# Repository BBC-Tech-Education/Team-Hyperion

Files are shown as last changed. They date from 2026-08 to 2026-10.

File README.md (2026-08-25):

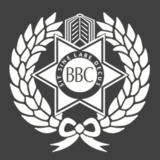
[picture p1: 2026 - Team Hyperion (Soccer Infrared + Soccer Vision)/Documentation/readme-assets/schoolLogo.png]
#  TEAM HYPERION 
### Brisbane Boys' College · RoboCup Junior Soccer Squad

<p align="center">
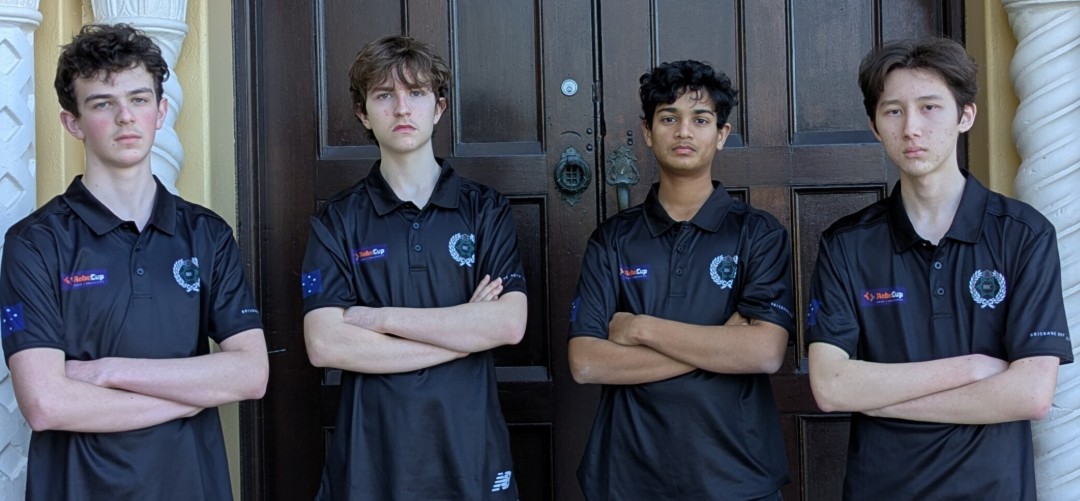
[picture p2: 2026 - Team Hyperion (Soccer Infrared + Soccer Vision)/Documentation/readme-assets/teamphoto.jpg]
Team Hyperion Banner
  
  <br>
  <b>Green. White. Black. Representing Australia.</b>
</p>

## 🤖 MISSION: BUILT TO COMPETE
Team Hyperion is a dedicated group of high school students (**Sam, Matthew, Luke, and Thomas**) from **Brisbane Boys' College** in Queensland, Australia. Originally competing internationally in Lightweight Soccer, we now compete in the **Soccer Vision League**—combining advanced robotics, autonomous alogorithms, custom sensor arrays, and precision engineering on the world stage.

---

## 🏆 ACHIEVEMENTS & COMPETITION HIGHLIGHTS

- **2026 RoboCup Junior International (Incheon, South Korea):**
  - **12th Place** — Individual Soccer (Improved ranking from 2025)
  - **4th Place** — SuperTeam Competition
- **2025 Australian National Competition:**
  - **Undefeated National Champions** — Reclaimed Australia's qualification spot for 2026
- **2025 RoboCup Junior International (Salvador, Brazil):**
  - **1st Place** — Lightweight SuperTeam World Champions
  - **14th Place** — Individual Lightweight Soccer

---

## 🚀 CURRENT CAMPAIGN (2026)
Having recently returned from the **2026 RoboCup Junior World Championship in Incheon, South Korea**, Team Hyperion is currently preparing for upcoming events, including the **Australian National Competition on the 3rd of October** in the Soccer Vision League.

---

## 🔗 CONNECT WITH US
Stay updated with our technical progress, media features, logbook, and competition results:

| Platform | Link |
| :--- | :--- |
| **🌐 Official Website** | [Visit Hyperion Online](https://team-hyperion-bbc-robotics.github.io/) |
| **📺 YouTube Channel** | [Watch Us Compete (@hyperion-bbcrobotics)](https://www.youtube.com/@hyperion-bbcrobotics) |
| **📓 Engineering Logbook** | [View Our Development Process](https://team-hyperion-bbc-robotics.github.io/logbook.html) |
| **✉️ Contact Email** | [bbchyperion@gmail.com](mailto:bbchyperion@gmail.com) |
| **📜 Legacy Sites** | [2024 Site](https://team-hyperion-bbc-robotics.github.io/2024) · [2025 Site](https://team-hyperion-bbc-robotics.github.io/2025) |

---

## 🛠️ THE TECHNOLOGY
Our custom-engineered robot stack is designed for high-speed autonomous play:
- **CAD & Mechanical Design:** Full 3D component renders in Fusion 360.
- **Lightweight League - Custom IR Ball Detection (Legacy Hardware):** TSSP77038 sensor ring tailored for direct IR tracking and direction strength processing under updated RCJ regulations.
- **Software & Vision:** Custom algorithms for ball tracking, autonomous navigation, and dynamic field positioning in the Soccer Vision League.

---

<p align="center">
  <i>"This is College" — Representing Brisbane Boys' College on the World Stage</i>
</p>

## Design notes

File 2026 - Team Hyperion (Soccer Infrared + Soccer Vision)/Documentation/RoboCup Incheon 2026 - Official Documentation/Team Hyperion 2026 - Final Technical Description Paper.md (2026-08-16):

## Timestamp

*Tijdstempel*

28-6-2026 16:23:18

## Email Address

*E-mailadres*

aparaj.bogahawatta@gmail.com

## TDP File

*TDP File Upload (Not required)*

## Team Name

*What is your team's name?*

Hyperion

## League

*What league do you participate in?*

IR League

## Country

*Where are you from?*

Brisbane, Queensland, Australia

## Contact

*If other teams have questions about your robot, now or in the future, what email address(es) can we publish along with this document for people to reach you?

(You can put in multiple email addresses, like multiple team members, an email for the whole team or both. Feel free to share other ways of communication like Discord handles)*

Team Hyperion Email: hyperionbbc@gmail.com

## Social Media

*Team Social Media Links (if you have any)*

YT: https://www.youtube.com/@hyperion-bbcrobotics

## Team Photo

*Upload a photo of your whole team with your mentor and robots

Note: This is not mandatory and will be published along with your TDP if you choose to upload something*



## Members & Roles

*What are the names of the team members and their role(s)?*

Matthew Adams: Electrical
Luke Atherton: Structural
Sam Garg: Software (Strategy)
Thomas McCabe: Software (Vision)

## Meeting Frequency

*How often did your team meet?
(e.g. 90 minutes once per week or a day every weekend.)*

During school term: 2.5 hours twice per week. During holidays: 4 hours three times per week

## Meeting Place

*Where did you meet to work on your robot?
(e.g. a robotics room at school, at some other place, one of your homes, school library etc.)*

We meet at our school’s designated robotics lab, the Brisbane Boys’ College Robotics Lab.

## Start Date

*When did your team start working on this year's robot?*

October 2025, after Australian Nationals

## Past Competitions

*Which RoboCupJunior competitions have you competed in and in which leagues?*

Brisbane Regional Competition 2026: Lightweight Soccer
Australian National Championship 2025: Lightweight Soccer
Queensland State Championship 2025: Lightweight Soccer
International Championship 2025: Lightweight Soccer
Australian National Championship 2024: Lightweight Soccer
Queensland State Championship 2024: Lightweight Soccer
Brisbane Regional Competition 2024: Lightweight Soccer

## Mentor Contribution

*Which parts of your work received the most contribution from your mentor?*

Our mentor assisted to debug electrical issues with the kicker PCB and our Out of bounds algorithm with the light sensors.

## Workload Management

*How did you manage the workload?*

By communicating via Teams, WhatsApp, and Discord, and using to-do lists and work logs, we managed our workload efficiently! This consistent workflow helps track our robot's progress, saves time, and cuts out redundant tasks.

## AI Tools

*Which AI tools did you use?*

We use Gemini for coding practices, field strategies, and docs, and Claude Code to design an aesthetic, secure website.

## Robot1 Overall

*Robot 1 Overall View*



## Robot1 Front

*Robot 1 Front view*



## Robot1 Back

*Robot 1 Back view*



## Robot1 Top

*Robot 1 Top View*



## Robot1 Bottom

*Robot 1 Bottom View*



## Robot1 Right

*Robot 1 Right View*



## Robot1 Left

*Robot 1 Left View*



## Robot2 Overall

*Robot 2 Overall View*



## Robot2 Front

*Robot 2 Front view*



## Robot2 Back

*Robot 2 Back view*



## Robot2 Top

*Robot 2 Top View*



## Robot2 Bottom

*Robot 2 Bottom View*



## Robot2 Right

*Robot 2 Right View*



## Robot2 Left

*Robot 2 Left View*



## Mechanical Design

*How did you design the mechanical parts of your robots?*

Using Autodesk Fusion 360, we upgraded our previous robot by adding a kicker, dribbler, and custom dual-layer omni wheels. To offset the added weight, we optimised existing components to minimise mass while ensuring structural strength. Key changes included designing a compact, high-stability wheel hub and heavily modifying the internal layout to fit the new mechanical systems alongside the PCBs and motors.

## Build Method

*How did you build your design?*

We manufacture parts using Bambu Lab 3D printers (PLA/ABS) and a CNC miller for 3mm aluminium plates. PCBs are ordered from JLCPCB, with components mainly sourced via Digikey. PCBs were hand soldered.

## Motors & Reason

*How many motors have you used and why?*

The robot features an X-shaped drive system with four 3D-printed-bracket-mounted Maxon DCX19 motors for omnidirectional movement without rotation. Overvolted at 12V for extra speed and torque, they power custom dual-layer omni wheels. These wheels use durable ABS frames and silicone-moulded rollers on metal cores, maximising traction, surface contact, and stability during competitive play.

## Kicker Design

*If your robot has a kicker, explain how you designed and built the mechanics of the kicker*

Our kicker uses a modified TAKAHA CB1037 solenoid with a custom 250-turn coil and a lightweight 3D-printed casing. The standard tip was replaced with a horizontal bar for reliable ball contact. Powered via a voltage booster that jumps 12V to 48V, it delivers a significantly stronger kick.

## Dribbler Design

*If your robot has a dribbler, explain how you designed and built the mechanics of the dribbler.*

Our dribbler uses a 3D-printed housing with a 1:4 speed-multiplying gear train, running the motor efficiently while spinning the roller at high velocities to save power. The roller features silicone molded around a 3D-printed rod to maximize grip and prevent ball slippage in the capture zone.

## CAD Files

*CAD design files*

https://github.com/Team-Hyperion-BBC-Robotics/Team-Hyperion/tree/main/2026%20(RCJ%20Lightweight%20Soccer%20and%20Open%20Soccer)/Hardware

## Mechanical Innovation

*Mechanical Innovation*

Our most significant innovation was a custom wheel hub, inspired by previous models, designed to attach our dual-layered omni wheels. This integration achieved better traction on the slippery felt field.

The hub directly modifies our existing design by adding a specialised internal groove for a square nut. This allows a bolt to tighten directly onto the motor's D-shaft, ensuring a secure mechanical connection that eliminates the risk of the wheel sliding off the axle.

## Mechanical Photos

*Photos of your mechanical designs highlights*




## Electronics Block Diagram

*Provide us with a block diagram of your robot's electronics*



## Power Circuit

*How does your power circuits work?*

A 12.6V LiPo battery powers the motors and kicker directly. Buck converters step this down to 5V (for the Teensys, camera, Bluetooth, and photogate) and 3.3V (for the IMU, IR sensors, and light ring), ensuring a stable, regulated power supply across all components.

## Motor Drive Circuit

*How do you drive your motors? Explain the circuits you use for that*

The robot uses five VNH7070 motor drivers powered directly by the battery. Four drivers control the drive system, receiving PWM commands from dual Teensy 4.1 microcontrollers to regulate each motor's speed and direction, enabling precise and powerful omnidirectional movement.

## Microcontroller & Reason

*What kind of micro controller or board do you use for your robot? Why did you decide to use this part for your robot? If you have more than 1 processor, explain each one separately.*

We use two Teensy 4.1 microcontrollers. One MCU reads the 24 TSSP sensors and communicates the ball data to the primary MCU via UART. The primary MCU reads the light sensors, IMU, receives the ball data and drives the motors and kicker.

## Motor Control

*How do you use your processor to move your motors?*

Exit VNH7070 standby: hold InA and InB HIGH for at least 20us. To drive, set one LOW, the other HIGH, while modulating PWM for speed. Both HIGH locks the motor; both LOW coasts. To coordinate, the processor uses a cosine function to calculate exact speed and direction for each motor.

## Ball Detection

*How does your ball detection sensors and/or camera[s] work?*

Our system detects a 40kHz IR ball using TSSP77038TR sensors. The ball's 24% duty cycle is polled over a 10ms window to locate it. To ensure stability, an Exponential Moving Average (EMA) filter smooths the data and remove high frequency noise on the readings. We then treat each value as a vector and sum them to determine the ball direction and strength.

## Line Detection

*How does your line detection circuits work?*

The robot has 48 LEDs/phototransistors. These are multiplexed using 3x 16 channel multiplexers for the primary MCU to read. 32 sensors are arranged in a ring and the other 16 are placed on the edge of the robot for early line detection.

## Navigation/Position Sensors

*What sensors do you use for navigation and how are these sensors connected to your processor? What sensors do you use to find your position in the field? What about the direction your robot faces?*

Connected to a Teensy processor, our robot uses an OpenMV N6 Camera via UART for absolute positioning, calculating coordinates using trigonometry on blue and yellow goals. For heading, a BNO055 sensor connects via I2C. By setting a baseline orientation upon startup or software reset, it continuously tracks our true direction relative to the field, ensuring dynamically accurate movement.

## Kicker Circuit

*How do you drive your kicker system? How does the circuit make the kicker work?*

A 12V supply is boosted to 48V to charge two parallel 4700μF capacitors. The microcontroller monitors this charge via a voltage divider. Upon a command, two N-channel MOSFETs discharge the energy through the solenoid to kick. A manual button routes power through a 50Ω resistor to safely de-energize.

## Dribbler Circuit

*How does your dribbler system work? What components and circuits did you use to drive it?*

Our dribbler system is a fifth Maxon motor which its circuit is integrated into our main board and is powered the same as the drive motors.

## Schematics

*Schematics of your robot*







## PCB

*PCB of your robot*





## Electronics Innovation

*Electronics Innovations*

A key innovation in our design is the custom dual-ring light sensor board, which provides a fast and reliable line avoidance system. The board utilizes a total of 48 sensors arranged in two concentric rings: an outer ring of 32 sensors and an inner ring of 16 sensors. 

The 32 sensors on the outer ring are divided into four distinct directional zones (front, back, left, and right) to provide rapid boundary detection and early warning alerts. The inner ring of 16 sensors serves as the primary trigger, signalling the robot to execute immediate corrective manoeuvres to remain within bounds. 

Integrating all 48 sensors into a single, consolidated printed circuit board (PCB) significantly reduces internal wiring. This layout minimizes the risk of loose connections and simplifies troubleshooting by allowing for rapid fault isolation.

## Circuit Photos

*Photo of your circuit boards highlights*







## Ball Detection Method

*How do you find where the ball is? How do you read the data from the ball detection sensors and/or camera?*

To locate the ball, our robot rapidly polls 24 IR sensors over a 20-millisecond window to count detected light pulses. These raw counts are normalised against the ball's duty cycle and smoothed by an EMA filter to prevent erratic spikes. Vector summation then resolves the exact relative angle. The magnitude is scaled to 0-100% for distance and sent via UART to the processor.

## Ball Catch Algorithm

*How does your algorithm work to catch the ball? Is there a difference between your robots in how they move towards the ball? Explain the differences.*

Our two-Teensy system uses a secondary Teensy to read IR sensors, pinpointing the ball's angle and distance without a camera. The primary Teensy uses this data to steer a smooth, curved orbit behind the ball, slowing for sharp turns and surging forward when perfectly aligned. This fluid approach replaces an older, twitchy method that ignored distance and glitched across the center line.

## Positioning Algorithm

*How do you use your sensors in your algorithm to find your position inside the field and how do you use that position to move your robots around?*

Using a camera to spot coloured goals, the robot calculates distance by size and notes the angle. Combining this with a digital compass, it pinpoints exact field coordinates. It navigates by plotting a straight line to the target, smoothly setting speed and direction. When the ball is off-field, this system centers the robot, ensuring the fastest route to the next ball.

## Line Algorithm

*How does your robot find the lines to stay inside the field? What algorithms do you use to avoid going out of bounds?*

Our robot multiplexes 48 light sensors, using dynamic calibration to isolate white lines. A Center of Mass algorithm generates a raw line vector from these active sensors. This vector is compass-corrected for field relativity and processed by a state machine tracking crossing depth. Finally, a PID controller uses this data to dynamically scale recovery speed in the exact opposite direction.

## Goal Algorithm

*What algorithms do you use to score goals? How do you use your kicker and dribbler to handle the ball?*

To score efficiently, our software merges orbit and goal-tracking algorithms using TSSP sensors and a camera. The orbit algorithm calculates an offset to position the robot behind the ball. Upon contact, an active dribbler firmly secures it, preventing wasted kicks and enabling passes. Using camera data, the robot dynamically aligns with the goal and triggers a powerful, calculated kick.

## Defense Algorithm

*What algorithms do you use to avoid the opponent team scoring? How do your robots defend your own goal?*

Our defender uses three PID controllers. A rotational PID keeps the robot facing away from the goal. The vertical PID controls depth via line sensors, using camera distance if the line is lost. The horizontal PID centres the robot, or laterally mirrors the ball to block shots. Combining these outputs into one resultant vector ensures fluid, omnidirectional movement to protect the goal.

## Robot Communication

*Do your robots communicate with each other? How do you use this communication to your advantage?*

The robots communicate via bluetooth assigning roles based on a 100-point score. The ball proximity (40pts), front attack cone (20), goal alignment (15), defensive distance (15), and battery health (10) are the factors the algorithm will consider. The robot with the highest score attacks. If one robot is taken off, then the remaining robot defends the goal.

## Software Innovation

*Software Innovations*

Our proudest innovation is a multi-stage IR sensor pipeline to track a 40kHz pulsed ball. We rapidly poll 24 TSSP77038TR sensors 500 times per 10ms window. To prevent jitter, an EMA filter blends this with historical data, halving standard deviation to 0.47. A vector summation calculates exact relative angles, while raw magnitude (110-130) is scaled to a 0-100% value. This information is sent to the main controller to determine motor movements.

## GitHub Link

*GitHub link*

https://github.com/Team-Hyperion-BBC-Robotics/Team-Hyperion

## BOM

*Bill of Materials (BOM)*

[https://drive.google.com/open?id=1605ioj5zMtxmfVHzTSfSkzvatkaK7vDL](https://drive.google.com/open?id=1605ioj5zMtxmfVHzTSfSkzvatkaK7vDL)

## Cost

*How much did it cost you to build your robots?*

Robots: $3,834 AUD (~$2,530 USD)

Spares & Experiments: $1,550 AUD (~$1,023 USD)

Environment: $0 AUD (Reused)

Total: $5,384 AUD (~$3,553 USD)

Conversion rate: 1 AUD = 0.66 USD

## Funding

*How did you gathered the funds to build the robots?*

100% School

## Affordability

*How affordable was it to compete in RoboCupJunior Soccer?*

5

## Answer Check

*Have you checked all of your answers?*

Yes!

## Publication Consent

*We publish TDPs and posters during or after the competition as described in the beginning*

Yes, we acknowledge everything submitted in the above form can be published.

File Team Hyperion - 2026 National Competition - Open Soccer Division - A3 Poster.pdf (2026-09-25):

# TEAM HYPERION

# Brisbane Boys’ College - Open Soccer League - Australian National Competition

### Who are we?

We are Team Hyperion, a four-student robotics team from Brisbane Boys' College, and right now, our primary focus is gearing up for the National Competition in the Open Soccer Division. We have just returned from representing Australia at the 2026 RoboCup in Incheon, South Korea, where we secured 12th Place Individually and 4th Place in SuperTeam, which proudly builds on our 2025 run in Salvador, Brazil (14th Individually, 1st Place SuperTeam). Coming off those international campaigns in the Infrared league, we are currently executing rapid technical modifications to our robot system adjusting our 360° vision processing and movement algorithms to handle the new field conditions of the Open league. After a quick trial run during the Queensland state competition, we are incredibly excited to compete in the national competition this year.

Previous Competition
Experience

2026 Queensland States
2026 Internationals - South Korea 2026 Brisbane Regionals
2025 Australian Nationals -Canberra
2025 Queensland States
2025 Internationals - Brazil 2024 Australian Nationals -Queensland
2024 Queensland States
2024 Brisbane Regionals
+ Numerous Individual
RoboCup Competition
Experience

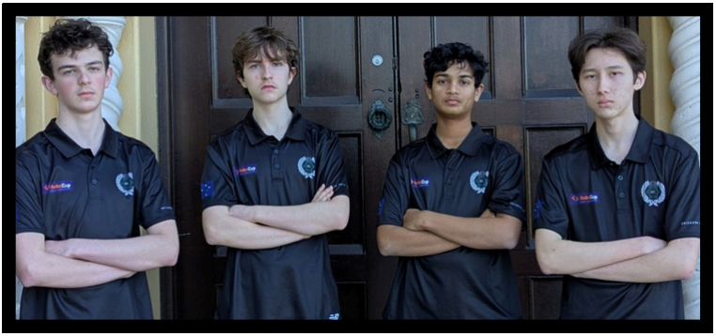
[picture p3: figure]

Our Team (Left to Right)

Thomas McCabe - Sensors/Software Luke Atherton - Structural/Hardware Sam Garg - Strategy/Software Matthew Adams - Electrical/Hardware

### Our Innovations - Light Sensor Board & Kicker “Video Game” Software

Hardware Innovation: The Light Sensor Board
The Light Sensor Board features 48 distinct component groups, each equipped with phototransistors, LEDs, resistors, and smoothing capacitors. These sensors are strategically arranged in a circular pattern ahead of the wheels to optimise a defender's positioning near the goal box, while 16 outer groups are divided into four segments between the wheels to ensure rapid line detection and response. To manage this dense array efficiently, all sensor signals are routed through three 16-bit multiplexers. This hardware configuration successfully consolidates the multiplexed data into just four analog pins, significantly reducing the number of processor pins required for operation.

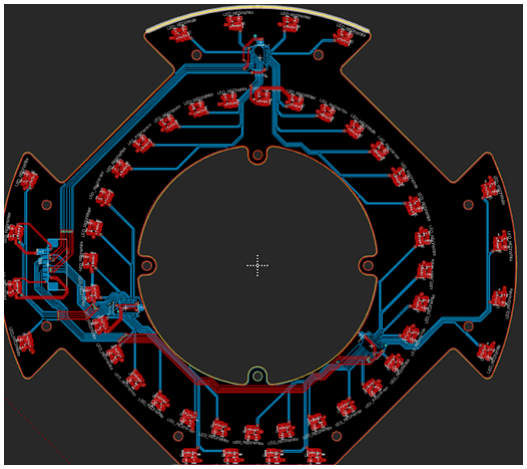
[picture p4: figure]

Software Innovations: The Ball Handling “Video Game” Software
The Kicker Software operates almost like a video game. This coded library coordinates the robot’s ability to safely shoot the ball automatically, acting as a strict “safety checklist” to prevent weak, accidental, or dangerous solenoid triggers. For example, one checklist item ensures the kicker has over 40V of stored power before firing. Just like an energy meter in a game, the robot holds a maximum of 5 kicks at any given time. When it does kick, it requires 20 seconds to recharge before that kick can be replenished, which prevents the hardware from overheating and causing a potential safety hazard. Additionally, the software enforces a mandatory 5s cooldown timer after every kick to allow the electronics to safely recover. To precisely time the shot, the kicker system uses a light gate made from a simple laser pointed directly into a light-dependent resistor (LDR). When a ball rolls into the capture zone, it blocks the beam of light from reaching the sensor. This causes the LDR's reading to drop, instantly signaling to the system that the ball has entered the capture zone. Finally, to ensure maximum hardware safety, a small LED on top of the robot’s PCB illuminates whenever there is voltage stored within the capacitors. If the capacitors still hold a charge when the robot is turned off, the system's fuse may blow. This warning LED lets team members know exactly when voltage is still present, ensuring the capacitors can be safely drained before powering down the robot.

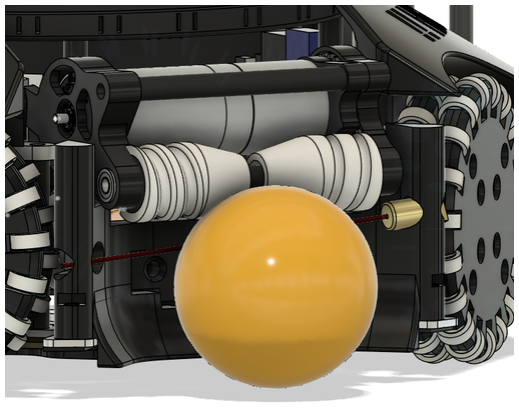
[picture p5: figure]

### Our Challenge – Ball Control & Field Vision

The Challenge: The robot struggled to maintain ball control and create scoring opportunities. Our previous momentum-based approach was ineffective under the international field restrictions and caused gradual damage through collisions with opponents. Additionally, the reflective-foil mirror used for goal and ball tracking was unreliable. Its steep viewing angle and surface warping created significant blind spots, limiting the camera’s ability to consistently detect and track the ball and goals.

The Solution: The team engineered a custom kicker and dribbler system. The dribbler uses a 3D-printed housing with a 1:2.81 speed-increasing gear ratio and high-grip silicone roller for reliable ball control. The kicker uses a modified TAKAHA solenoid with a custom hand-wound coil, lightweight 3D-printed mount, and wide plunger tip for consistent contact across the capture zone. A voltage booster increases the supply from 12 V to ~48 V, substantially increasing kicking power, while an integrated photogate detects ball capture.
A custom CNC-machined hyperbolic aluminium mirror was manufactured and polished. Its reflective curvature was calculated in Desmos based on the robot's dimensions and desired viewing range.

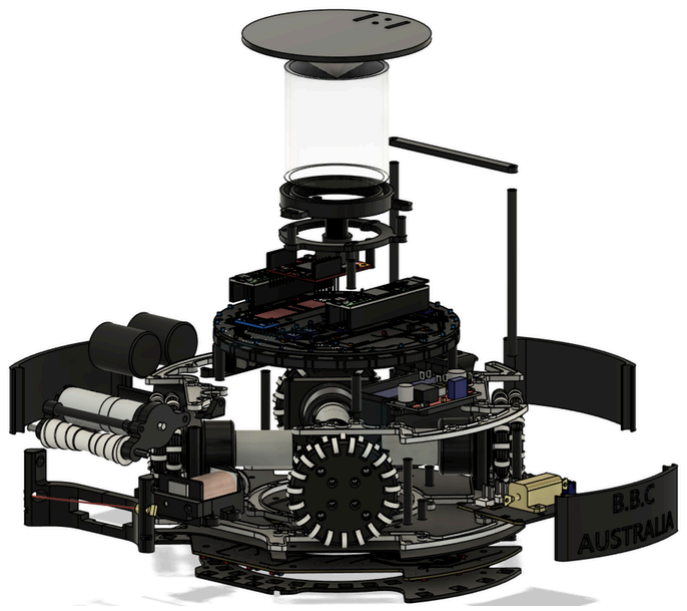
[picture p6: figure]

### What have we learnt throughout our time at RoboCup?

Throughout our time at RoboCup, we have experienced highs and lows. Whether that was the unparalleled thrill of placing in a competition, or the absolute panic of our robot’s wheels disintegrating right before a match, we have experienced a lot of what RoboCup has to offer. As a result of this, there are many things that we have learnt. This includes valuable technical and coding skills that we can take into our future professions and use to stand out in job applications. Moving beyond basic programming, we evolved into ‘multidisciplinary’ engineers. Structurally, we learned how to design resilient robots and account for the brutal physical forces our robots would face on the field. Electrically, we tackled power distribution, soldered reliable connections, and ensured clean signal integrity between components. By combining this hardware knowledge with complex software logic to process sensor data in milliseconds, we truly learned how to bridge the gap between digital code and the unpredictable physical world. However, the most profound lessons haven't just been technical. We have also grown significantly as a team over the years, which has given us the valuable ability to communicate, collaborate, and thrive under immense pressure. We learned how to divide tasks based on our individual strengths, trust one another's expertise, and navigate the high-stress environment of competition days by turning disagreements over design choices into constructive compromises. Most importantly, watching our hard work occasionally fall apart on the mat taught us true resilience. We learned to treat failures not as personal defeats, but as crucial data points to improve our iterative design. Ultimately, RoboCup was never just about making a robot function; it was a pressure cooker that forged us into better problem solvers and a more cohesive team, building a foundation of grit and synergy that will outlast any tournament.

## Our Website

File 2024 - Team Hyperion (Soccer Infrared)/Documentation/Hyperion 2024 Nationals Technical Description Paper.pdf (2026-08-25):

© RoboCup Junior Australia 2024 | 1 | P a g e

2024

## RCJA 2024 Rescue Line, Rescue Maze and Soccer Technical Description Paper

## Team Information: Challenge/Division: Lightweight soccer Team Name: Hyperion School: Brisbane Boys’ College State/Territory: Queensland - Brisbane Team Member Names:

If any team member had a specific role, please include this below.

## Member 1: Matthew Adams (Electrical) Member 2: Luke Atherton (Hardware) Member 3: Sam Garg (Software)

Robot Properties: (200 words recommended maximum, plus components list (if applicable))

Please describe the software (e.g. EV3 Block Code, Python) and hardware (e.g. Spike Prime, EV3, Raspberry Pi) you have used for your robot.

For each piece of software/hardware used, please give it a star rating out of 5 (1=very bad, would not recommend to other teams, 5=very good, would strongly recommend to other teams).

If you have used custom electronics for your robot, please include specific model/part numbers or web links, and a star rating for each.
Software
- The main language used for our robot is C++, however, python was used to communicate to a camera (in a library that is not used yet). An Arduino programming style was chosen to do this. A compiler was used so that the Arduino language can be understood by the robot. This compiler is named ‘platformio’ and is a commonly based system that is used for various programs.
C++ = 5
Arduino programming style = 4
Platformio = 5

Hardware
- Within the hardware process, Fusion 360 was used to design our full robot design, various individuals 3d printed components (such as the battery holder) and PCBs (such as the Light Sensor Board). Fusion also allowed for parts which weren’t printed to be factored into the visual design (such as various stand-offs between plates and components). Our robot mainly consists of a Base plate, Mid plate, Top plate, motor holders and TSSP holder made from PLA 3D print filament. With other smaller 3d printed parts to support other components, such as the battery holder, and 3d printed plates to support the power supply and Audino. There are 4 motors positioned in an X shape because of our omni wheels which allows the robot to have smooth omni-directional movement, being able to move in all directions with minimal issues, ensuring precision when positioning the robot on the field for optimal play. The central positioning of the power supply allowed for wires to connect easily to both the Audino and motor controllers.
Electrical
- The Electronic components consist of a power supply board, Light sensor Board and TSSP board. The Power Supply Board is a 60Lx40W(mm) board consisting of a JT60 connector that is connected to a 12V 1.3Amp Battery that is tucked in the robot securely, also there are multiple connections for power output on top of the board. The TSSP ring board is a circular ring with a hole in the centre to save space. The diameter of the board is 80mm the which is the exact size of the holder that we made. The TSSP ring is consisted of jumper wire pins and 12 TSSP58038 components in a circular patten pointed outwards. The Light sensor board is made of 16 Red LED’s and sensors in a circular patten.
Components List
- 3D Printed Custom Parts
- Custom made PCB’s (Light Sensor ring Board, Power Supply Board and TSSP ring board)

© RoboCup Junior Australia 2024 | 2 | P a g e
- Wheel rollers = 3
- Polulu 9.7:1 Metal Gearmotor 25Dx48L mm HP 12V https://www.pololu.com/product/3202 = 3
- Electrical Wiring
- Hot Glue
- Screws
- Nuts
- Bolts
- Standoffs = 5
- TSSP58038 TSSP58038 Vishay Semiconductor Opto Division | Sensors, Transducers | DigiKey (https://www.digikey.com.au/en/products/detail/vishay-semiconductor-opto-division/TSSP58038/4695717) = 4
- Arduino Jumper wires https://www.jaycar.com.au/150mm-plug-to-socket-jumper-leads-40-pieces/p/WC6028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 (https://www.jaycar.com.au/150mm-plug-to-socket-jumper-leads-40-pieces/p/WC6028) = 3
- MPU 9250 https://www.phippselectronics.com/product/mpu9250-9-axis-motion-sensor-module-accelerometer-gyroscopecompassmotion/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 (https://www.phippselectronics.com/product/mpu9250-9-axis-motion-sensor-module-accelerometer-gyroscope-compass-motion/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) = 3
- Arduino Mega 2560 = 4
- Multiplexer (for LSB) https://octopart.com/adg1206yruz-reel7-analog+devices-46514718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 (https://octopart.com/adg1206yruz-reel7-analog+devices-46514718?gad_source=1) = 3
Collaboration: (100 words recommended maximum)

### Please describe if your team has used any methodologies, software or systems to aid collaboration (working together). This could be related to the design, construction or

programming of the robot(s).
It is the overall desire of RoboCup Junior events that any technological and curricular developments will be shared with other participants after the event. Any developments including new technology and software examples, may be published on the RoboCup Junior website after the event, furthering the mission of RoboCup Junior as an educational initiative.
To collaborate we use Microsoft Teams, in the BBC Robotics Team (Organization)- we have our own designated channel. As well as this, we chat to each other using the teams group chat feature. (Also, by phone if teams are not available)

In addition to this; we use Fusion 360 to communicate our changes within our robot’s design. This allowed for all to make changes and access the full design, various components, and PCBs.

Not only this; but we use GitHub to communicate the changes made within our code, and so that all could access an updated version and previous versions of the code.

## Key Achievement & Area for Improvement: (300 words recommended maximum)

### Please describe one aspect of your robot your team is particularly proud of, and one

aspect you would like to further improve.
We are particularly proud of the way our TSSPs are designed- it can be seen that we use a PCB that links to the Arduino and power supply. Since we are a new team this year, PCBs are not regularly given- howeverthis was an exception, and we did not fail to deliver.

Another aspect that is particularly well done- is the overall design of the base & mid-plate. It is extremely organised and allows for a tight & compact robot, with components attaching both above and below the board. The various gaps in the board allows for reduced weight and allows for wires to connects to various components both above and below the mid-plate, such as between the motor controllers and the power supply. The mid-plate is compact as it has both components and standoffs above and below it; being attached to the motor brackets, motor controllers, standoffs to the baseplate, standoffs to the top-plate, standoffs to the power supply, and standoffs to the TSSP ring. Not only this- but our capture zone is the perfect size, allowing us to capture the ball within the rules- but also be able to dribble it.

In addition to this, we could introduce goal tracking to ensure that our robot faces the goal when we accelerate, to allow for more accurate goals, with more consistency.

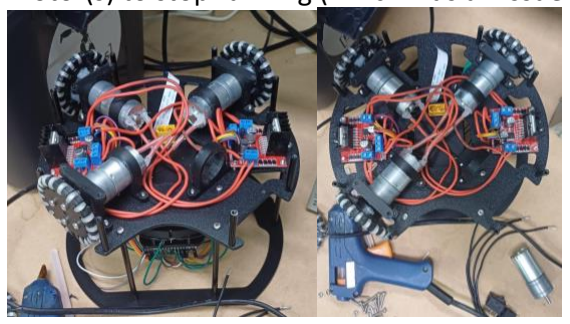
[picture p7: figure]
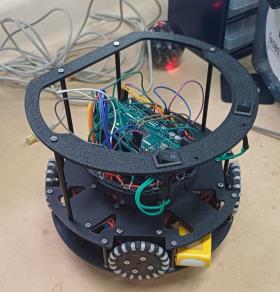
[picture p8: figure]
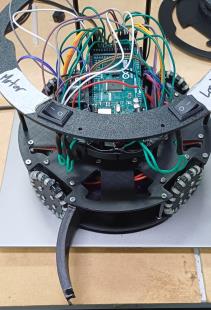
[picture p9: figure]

© RoboCup Junior Australia 2024 | 3 | P a g e

Photos and Design Documentation: (100 words recommended maximum, plus images)

### If there is a design drawing of the robot or if you have photos or notes of the

development process, please provide these as proof of your team’s learning.
These two images display the robot being assembled, with the wires from the motor controllers to the motors being soldered and hot glue gunned on to ensure they do not detach and cause the motor(s) to stop running (which was an issue we faced in earlier testing of the robot)

This image shows the assembled 1st robot. It consists of a top-plate, with 2 switches (one for motors and 1 for logic). It also has an Audino with wires to and from various components including the TSSPs on the TSSP ring and the power supply (located on a small plate just above the mid-plate). On the mid plate, above there are standoffs to the TSSP ring and top plate, and below there are the 2 motor controllers, motor brackets, and standoffs to the baseplate.

This image shows the robot with the battery holder attached (which stops the battery from falling out of the robot). The battery holder attaches to the standoffs as seen in the image, and it is also one of the later 3d printed components that were made. Previously, only tape was used but this was decided on as it would be more reliable and allowed for easier access the removal and reapplication of tape.

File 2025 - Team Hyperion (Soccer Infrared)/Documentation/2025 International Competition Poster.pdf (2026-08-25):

# Robocup Junior Soccer:

Lightweight Division | HYPERION
| BRISBANE BOYS COLLEGE

## > Robot Hardware Overview [Methods/Production/Design]

PHOTO HERE

# Method / Production / Design

# Abstract

Software Logic Flowchart

Electrical Logic Flowchart

# Data / Results / Discussion

## > Software Strategy [Methods/Production/Design]

## > Electrical Overview [Methods/Production/Design]

We use 2 customly designed PCBs which are an Intergreated Main Board and a Light Sensor Board.
1. Intergreated Main Board
The integrated main board includes a power supply circuit, Teensy 4.1, Open-MV H7 Plus, BNO055 IMU, Bluetooth HC-05 module, and a Light Sensor Board connected via an FFC connector. The power supply circuit is driven by a 3-cell 1300 mAh battery, which powers four VNH7070 motor controllers. It also includes 5V and 3.3V regulators that supply power to the microcontroller and 16 TSSP58038 sensors, respectively. The TSSP58038 sensors are arranged in a circular layout to provide a 360-degree view, allowing accurate detection of the ball’s position. The OpenMV H7 Plus was selected for its high detection speed, resolution, and frame rate.

The TSSP System library was custom-built by our team to meet specific design needs. It measures ball direction and strength by sampling each sensor 255 times, returning a value between 0 (no detection) and 255 (constant detection). A consistent 255 typically indicates a faulty sensor. If a single sensor fails, its value is replaced with the average of its two neighbouring sensors. However, software cannot correct clusters of failed sensors, which require hardware repair. Direction is now calculated using the top four TSSP readings, each weighted by its X and Y coordinates on the unit circle, with the angle derived using the arctangent function. Strength is determined through a weighted average: the strongest reading is multiplied by 3, the second by 2, and the third and fourth by 1, then divided by 7. This method improves accuracy and reliability in ball detection, with the example shown producing a strength of approximately 122.14 out of 255.

We utilise an OpenMV H7 Plus module, configured to a QQVGA resolution (160x120 pixels), which is then cropped to a 120x120 pixel square for processing. To identify both goals on the field, the robot employs the OpenMV camera to perform colour-based vision processing. Using Python, it runs the find_blobs function from the OpenMV image library, which detects coloured blobs that match a specified LAB threshold. The center coordinates of each detected blob are extracted and transmitted to the Teensy microcontroller via UART using the writechar function from the pyb UART library.

Hyperion is an Australian robotics team from Brisbane Boys’ College, competing in the 2025 RoboCup Junior Soccer Lightweight League. The team consists of four secondary school students who developed two fully autonomous soccer robots for the international competition. Building on experience from the 2024 season, our goal was to enhance the mechanical reliability, sensor accuracy, and gameplay consistency of our robots.
Each robot features custom-built omni-wheels for precise omni-directional movement, a vision system with a conical mirror and OpenMV camera for 360° goal tracking, and a light sensor array for field boundary detection. The robots are controlled using a Teensy 4.1 microcontrollers programmed in C++ via PlatformIO, with Micro-Python used for the OpenMV module. The robots were designed in Autodesk Fusion 360 and fabricated using 3D printing, CNC machining, and powered by custom-soldered PCBs.
To address limitations observed in past competitions, we refined the mirror geometry for improved goal visibility and replaced key structural components with aluminium to lower the centre of mass and increase impact resistance. We approached this season not just to compete, but to grow our technical capabilities and contribute to the wider RoboCup community. By documenting our designs and solutions for future teams to build upon, we aim to support RoboCup’s mission of fostering AI and robotics research.

When the robot detects a single cluster, it assumes the line is centered within that cluster and directly uses the cluster’s central angle as the estimated line direction. In the case where two distinct clusters are identified, the robot computes the circular average of their respective angles. This average is interpreted as the line direction, representing the midpoint between the two detected segments of the line. When three clusters are detected, the robot applies a more refined estimation method. It identifies the two outermost clusters based on angular separation and considers the remaining one as the central or inner cluster. First, it computes the average angle between each outer cluster and the inner cluster individually. These two intermediate values represent directional influences from each side of the line. Finally, it takes the average of those two values to derive a balanced and smoothed line direction, accounting for all three detected segments in a hierarchical manner.

An exponential function maps ball strength (distance to the ball) to the robot’s speed, enabling rapid acceleration when far and smooth deceleration when close. This improves control and reduces overshooting, unlike the slower-decelerating linear model previously tested. When the ball is directly ahead, the robot accelerates to top speed to maximise scoring.

To refine its movement path, the robot adjusts its trajectory using an exponential function based on ball direction. This creates a smooth, circular orbit around the ball, enabling fluid and strategic positioning for attack. Unlike using cases for where the ball is, and moving accordingly, this exponential function provides a more accurate and smooth orbit.

Ball Strength vs Movement Speed Graph

Ball Direction vs Movement Direction Graph

Previous Ball Direction Calculations vs Newly Innovated Ball Direction Calculations

Software

The first scenario prioritises ball strength, with the robot closer to the ball—indicated by higher strength—taking on the attacking role to maintain possession.

Bluetooth Switching, Scenario 1

Bluetooth Switching, Scenario 2

If the ball is behind the current attacker and closer to the defender, the robots switch roles minimising backtracking as the defender becomes the attacker and the original attacker takes a defensive role. This ensures the robot with the strongest visibility and least movement takes over the attack.

Camera Vision Example

Low/High Speed Moving Areas The attacker constantly advances toward the goal, guided by input from the onboard camera. It integrates this visual data into PID controllers, allowing it to quickly realign itself if displaced or rotated. Using the camera’s X-coordinate data, the robot estimates its lateral position on the field. When positioned closer to the sides—where the goal appears narrower—it reduces speed to enhance scoring accuracy. Conversely, it increases speed when directly in front of the goal, where the scoring angle is optimal.

Our defender uses three PID controllers to move effectively. The first is a rotation PID, which keeps the robot facing away from our goal at all times. This orientation ensures it is always prepared to intercept the ball as it approaches. The second is a vertical PID, which manages the robot's position relative to the goal. When the robot is far from the goal,
the control vector points at 180 degrees and increases in strength with distance. Conversely, when the robot is close to the goal, the vector strength decreases accordingly. The third PID responds to the ball’s position on the field. If the ball is to the right of the robot, it moves faster as the angle difference increases, and slower when the angle difference is smaller—though still quickly enough to position itself between the ball and the goal. When the ball is not present, the robot recentres itself in front of the goal using the compass, compensating for any offset caused by the rotation PID. If the ball moves behind the defender, the robot temporarily switches to attacker orbit behavior until the ball is once again in front.

Defender Vectors Example

1 Cluster Example | 2 Cluster Example | 3 Cluster Example

Flowcharts and Tools for Hardware and Software Hardware Tools

Software Tools

## Communication Tools

Autodesk
Fusion 360

Makera

Bambu Lab

Visual Studio Code

PlatformIO

OpenMV

Github

3D CAD
modelling
and PCB
circuit
design

CNC
machine
provider

Printing
3D models
for testing
& refining
Intergrated Main Board Fusion Design | Light Sensor Board Fusion Design
2. Light Sensor Board
The Light Sensor Board is comprised of 32 clusters of components, including phototransistors and LEDs arranged concentrically, and two 4-bit MUX506IPW to reduce Teensy pin usage. The Light Sensor Board allows our robot to distinguish boundary lines of the field (out of bounds, goal box) and specific edge cases where cross-shaped Light Sensor Boards cannot handle.

Aluminium Plate Replacement
We replaced PLA with aluminium 6061 for the mid and base plates to improve structural strength and gameplay durability. This change was prompted by repeated failures during high-speed matches, where abrupt impacts with the goal and other robots caused the PLA plates to crack or break, particularly at stress-concentrated regions.

Both of our robots are built on a shared design. Each robot features four motors, providing power, speed, and precise control for 360-degree movement. The goal of our robot design was to achieve a low centre of mass to improve acceleration, deceleration, and reduce tipping during turns. The frame was structured to compactly house all components without wasted space. We maintained a simple and focused design, prioritising only the components essential for consistent, reliable performance. Materials:
Three materials were used for the majority of the robot’s design: CNC-machined aluminium 6061, 3D-printed PLA, and 3D-printed ABS. The core structural plates for the robot were constructed from 3 mm thick CNC-machined aluminium, offering excellent strength, durability, and ductility, ensuring the robot’s structure remains intact after many collisions. The majority of other designed components were made using 3D-printed PLA due to ease of printing, decent strength and heat-resistant properties, and accessibility. 3D-printed ABS was used to construct the wheels, as, due to their close proximity and connection to the motors, they require very high heat resistance and greater durability compared to other printed components. Thus, ABS was used—as although it is more difficult to acquire and print, its superior performance in these properties makes it favourable for this component.

Vision System (1):
The vision system consists of a cone-shaped reflective mirror (1a), a clear acrylic tube (1b), an upward-facing OpenMV camera module (1c), and adjustable PLA mounting plates (1d).
- Mirror (1a) The mirror reflects a full 360° horizontal field of view down into the camera, allowing the robot to continuously track the goal from any position or orientation without needing multiple cameras.
- Tube (1b) The transparent acrylic tube connects the mirror and camera while allowing unobstructed light to pass through—unlike standoffs, it avoids introducing blind spots.
- Camera (1c) The OpenMV camera is programmed using MicroPython and processes the reflected image to determine the angle to the goal.
- Mount (1d) The adjustable plates allow for calibration of the mirror’s position to correct for alignment inconsistencies during manufacturing.

General Frame Design (2, 3, 4, 5):
The robot’s frame was designed around two main structural components:
- Top Plate (2) The top plate is 3D-printed in PLA and houses key switches and a handle for ease of access during matches.
- Battery Containment (3) The battery holder and a rear support wall between the mid and base plates, which secures the battery and prevents hardware failures caused by movement or impact.
- Mid & Base Plates (4 & 5) The mid plate and base plate, both made from CNC-machined aluminium to centralise mass low to the ground and improve stability during rapid movement.

Capture Zone (8):
The PLA-printed ball capture zone improves contact area with the ball, enabling more consistent control during movement and turns. Its curved design better matches the ball’s shape, reducing sudden contact and improving handling.

PCBs (7 & 10):
The PCB’s are designed in AutoDesk Fusion 360 and ordered through JLBPCB for fast and good quality boards. (More information in the Eletrical Overview)
- Light Sensor Board (7) The Light Sensor Board allows the robot to detect the boundary line and the Light sensor Board protector protects the Light Sensor Board from any debries left on the field.
- Main Board (10) The Main Board consists of the power supply, microcontrollers, motor controllers, bluetooth & camera.

Drive system (6: 6a, 6b, 6c):
The drive system consists of custom-made omni-directional wheels (6a), motor brackets (6b) and high-performance motors (6c)

The omni-wheels were designed with silicon-coated steel rollers mounted on ABS 3D-printed hubs for improved traction and durability.

Each wheel is powered by a DCX19 Maxon 9V motor (6c), due to its compact size and high torque output. The motors are fixed in place using custom brackets (6b), for alignment and structural stability.

CAD 3D Exploded view of overall Robot Structure In AutoDesk Fusion 360

3D Exploded view of Motor Mount In AutoDesk Fusion 360

Coding
software

Compiler
for microcontroller

Vision
programming
interface

Version
control &
collaboration

Discord

Microsoft
Teams

## Meet the Team:

Thomas McCabe | Luke Atherton | Samaksh Garg | Matthew Adams
Software & Documentation | Hardware & Structural | | Hardware & Electrical

Software &
Strategy

Team Communication and Collaboration, for scheduling sessions, progress updates, asking questions, and sharing files

Hardware

Mirror Dimension Simulation

Robots with PLA vs
Aluminium plates

Mass Increase and Centre of Mass Impact
- Aluminium plates added 101 g → Still under weight limit
- Extra mass lowered centre of mass
→ Improved stability during turns and acceleration
- Traction is the limiting factor for acceleration, not motor torque
→ Increased normal force enhanced grip without reducing speed
- Top plate remains PLA to minimise weight at higher elevations

Mirror Selection and Simulation
To maximise horizontal field of view and ensure uninterrupted vision of the goal, we investigated the optimal mirror shape and dimensions for our omnidirectional vision system.
Mirror Shape Investigation
- Cone-shaped mirror selected over 2D shapes (e.g. rectangles)
→ Reflects light from all horizontal angles into the camera → Enables full 360° vision around the robot
- Simplifies vision processing compared to using multiple cameras

Mirror Dimension Simulation
Fixed parameters: Base diameter (23.75 mm), vertical distance from camera to mirror base
Variable: Mirror height — determines reflection angle and field of view Goal: Find optimal mirror height for full field coverage
Method: Simulated ray reflections (mirror radius 2.375 cm) in Desmos
→ Adjusted mirror angle so reflected ray enters camera just below horizontal → Extended ray to floor (14 cm below camera) to find max range
Result: 16 mm mirror height → ~31 m viewing range (well beyond field, accounts for tolerances)

Innovations from 2024:
The main board was changed from multiple different PCBs to a single integrated PCB for easy access to all components and to limit the amount of space needed. The light sensor board was changed from a small ring with 16 groups of components to a ring surrounding the wheels of the robot with 32 groups of components to adapt to the different field and ruleset from the Australian Open in 2024.
PLA (previous) | Aluminium 6061 (current)
- Lightweight and easy to 3D print - Low yield strength (~60 MPa) and brittle - Fractures under stress, unsuitable for high-impact applications | - High mechanical strength (~270 MPa) and ductility - Plates deform slightly under stress rather than cracking - More reliable in high-impact applications
Our Website | Github Link

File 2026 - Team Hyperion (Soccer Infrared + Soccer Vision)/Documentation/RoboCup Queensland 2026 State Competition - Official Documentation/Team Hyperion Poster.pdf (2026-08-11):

# TEAM HYPERION

# Brisbane Boys’ College - Open Soccer League - Queensland State Competition

### Who are we?

We are Hyperion, a four-student robotics team from Brisbane Boys' College, and right now, our primary focus is gearing up for the Queensland Competition in the Open Soccer League. We have just returned from representing Australia at the 2026 RoboCup in Incheon, South Korea, where we secured 12th Place Individually and 4th Place in SuperTeam, which proudly builds on our 2025 run in Salvador, Brazil (14th Individually, 1st Place SuperTeam). Coming off those international campaigns in the Infrared league, we are currently executing rapid technical modifications to our robot system tweaking our 360° vision processing and movement algorithms to handle the new field conditions of the Open league. Despite the quick turnaround, we are incredibly excited to hit the state field and remain dedicated to sharing our open-source designs and workflows to help future teams master these advanced autonomous systems.

Previous Competition
Experience
2026 Internationals - South Korea
2026 Brisbane Regionals
2025 Australian Nationals -Canberra
2025 Queensland States
2025 Internationals - Brazil 2024 Australian Nationals -Queensland
2024 Queensland States
2024 Brisbane Regionals
+ Numerous Individual
RoboCup Competition
Experience


Our Team (Left to Right)

Thomas McCabe - Sensors/Software Luke Atherton - Structural/Hardware Sam Garg - Strategy/Software Matthew Adams - Electrical/Hardware

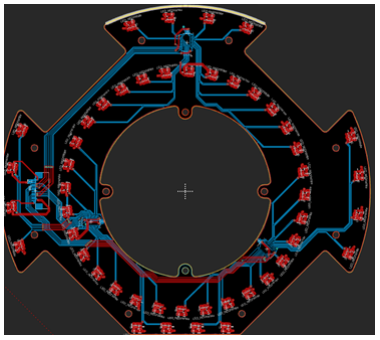
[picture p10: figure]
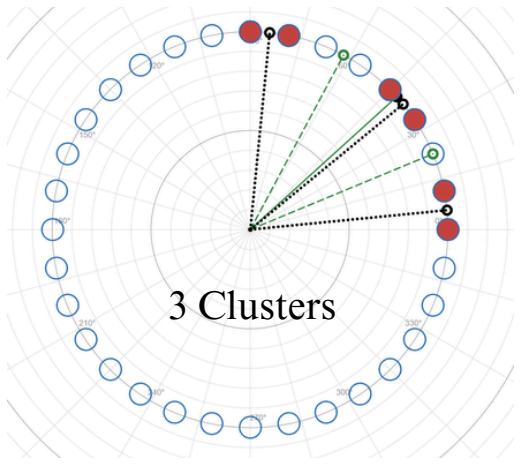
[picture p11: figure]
3 Clusters

### Our Innovation - Light Sensor Board

The Light Sensor Board features 48 distinct component groups, each equipped with phototransistors, LEDs, resistors, and smoothing capacitors. These sensors are strategically arranged in a circular pattern ahead of the wheels to optimize a defender's positioning near the goal box, while 16 outer groups are divided into four segments between the wheels to ensure rapid line detection and response. To manage this dense array efficiently, all sensor signals are routed through three 16-bit multiplexers. This hardware configuration successfully consolidates the multiplexed data into just four analog pins, significantly reducing the number of processor pins required for operation.

To find the direction of the line, the robot is simply trying to find the most accurate "middle" of whatever it currently sees. Depending on how many pieces (clusters) of the line the robot detects, here is what it does:
One Cluster: The line is straight at that cluster! The direction is just the center of that single piece.
Two Clusters: The line is in the middle of that cluster! The robot pinpoints exactly halfway between the two pieces.
Three Clusters: It completes a balancing act, where it finds the middle pieces and the two outside pieces. It calculates the halfway point between the middle and left side, and then the middle and right side. After doing this, it averages those two paths to get a smooth and balanced direction.

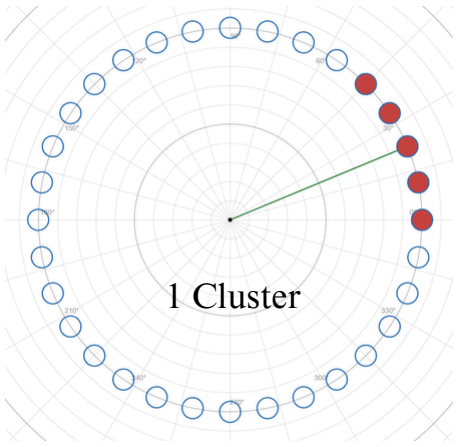
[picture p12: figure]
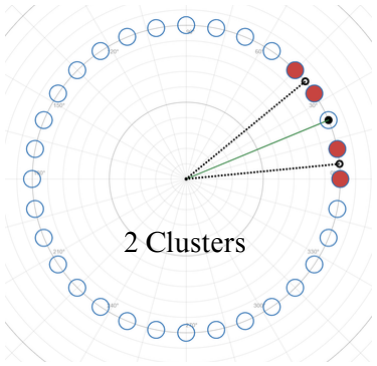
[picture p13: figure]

2 Clusters | 1 Cluster

### Our Challenge - Mechanical Stability, Traction and Weight & Kicker Designing

The Challenge: The robot struggled with traction on the slippery felt field, and there was a risk of the wheels sliding off the motor axles. Additionally, upgrading the robot with a new kicker, dribbler, and dual-layer wheels added unwanted mass (as we were previously in the Infrared Division, which had a strict weight limit).
The Solution: The team engineered custom dual-layered omni wheels with a specialised wheel hub. This hub features an internal groove for a square nut, allowing a bolt to tighten directly onto the motor's D-shaft for a highly secure connection. To offset the added weight of the new components, they optimized their existing parts and internal layout to minimize mass while maintaining structural strength.

The Challenge: Delivering a consistently powerful kick while ensuring reliable contact with the ball.
The Solution: The team heavily modified a TAKAHA CB1037 solenoid. They wound a custom 250-turn coil and replaced the standard tip with a horizontal bar to ensure reliable ball contact. To achieve the necessary power, they designed a circuit that boosts their 12V battery supply to 48V, charging two parallel 4700μF capacitors to discharge a massive burst of energy.

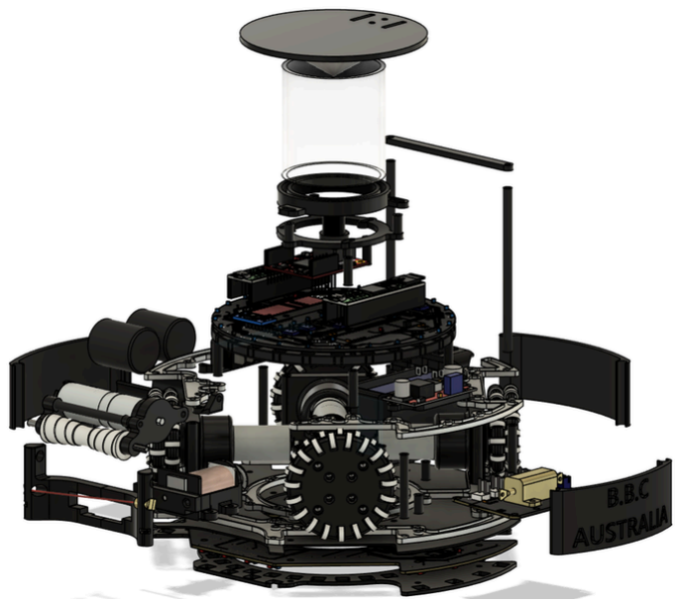
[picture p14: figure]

### What have we learnt throughout our time at RoboCup?

Throughout our time at RoboCup, we have experienced highs and lows. Whether that was the unparalleled thrill of placing in a competition, or the absolute panic of our robot’s wheels disintegrating right before a match, we have experienced a lot of what RoboCup has to offer. As a result of this, there are many things that we have learnt. This includes valuable technical and coding skills that we can take into our future professions and use to stand out in job applications. Moving beyond basic programming, we evolved into multidisciplinary engineers. Structurally, we learned how to design resilient robots and account for the brutal physical forces our robots would face on the field. Electrically, we tackled power distribution, soldered reliable connections, and ensured clean signal integrity between components. By combining this hardware knowledge with complex software logic to process sensor data in milliseconds, we truly learned how to bridge the gap between digital code and the unpredictable physical world. However, the most profound lessons haven't just been technical. We have also grown significantly as a team over the years, which has given us the valuable ability to communicate, collaborate, and thrive under immense pressure. We learned how to divide tasks based on our individual strengths, trust one another's expertise, and navigate the high-stress environment of competition days by turning disagreements over design choices into constructive compromises. Most importantly, watching our hard work occasionally fall apart on the mat taught us true resilience. We learned to treat failures not as personal defeats, but as crucial data points to improve our iterative design. Ultimately, RoboCup was never just about making a robot function; it was a pressure cooker that forged us into better problem solvers and a more cohesive team, building a foundation of grit and synergy that will outlast any tournament.

## Our Website

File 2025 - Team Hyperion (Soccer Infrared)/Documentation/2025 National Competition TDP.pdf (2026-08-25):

© RoboCup Junior Australia 2025 | 1 | P a g e

2025

## RCJA 2025 Rescue Line, Rescue Maze and Soccer Technical Description Paper

Team Information:
Challenge/Division: Lightweight Soccer Team Name: Hyperion
School: Brisbane Boys’ College
State/Territory: Queensland
Team Member Names:
If any team member had a specific role, please include this below. Member 1: Matthew Adams (Hardware, Electrical) Member 2: Sam Garg (Software, Movement & Avoidance)
Member 3: Luke Atherton (Hardware, Structural)
Member 4: Thomas McCabe (Software, Camera Vision)

Robot Properties (200 words recommended maximum, plus components list (if applicable))
Please describe the software (e.g. EV3 Block Code, Python) and hardware (e.g. Spike Prime, EV3, Raspberry Pi) you have used for your robot.

For each piece of software/hardware used, please give it a star rating out of 5 (1=very bad, would not recommend to other teams, 5=very good, would strongly recommend to other teams).

If you have used custom electronics for your robot, please include specific model/part numbers or web links, and a star rating for each.
Hardware:
Both of our robots are built on a shared design. Each robot features four motors, providing power, speed, and precise control for 360-degree movement. The goal of our robot design was to achieve a low centre of mass to improve acceleration, deceleration, and reduce tipping during turns. The frame was structured to compactly house all components without wasted space. We maintained a simple and focused design, prioritising only the components essential for consistent, reliable performance.

Materials:
The main materials used are CNC-machined aluminium 6061 for the core structural plates, 3D-printed PLA for most other components, and 3D-printed ABS for the wheels. Aluminium provides strength and durability, PLA offers ease of printing with good strength and heat resistance, and ABS is chosen for wheels due to its superior heat resistance and durability near the motors.

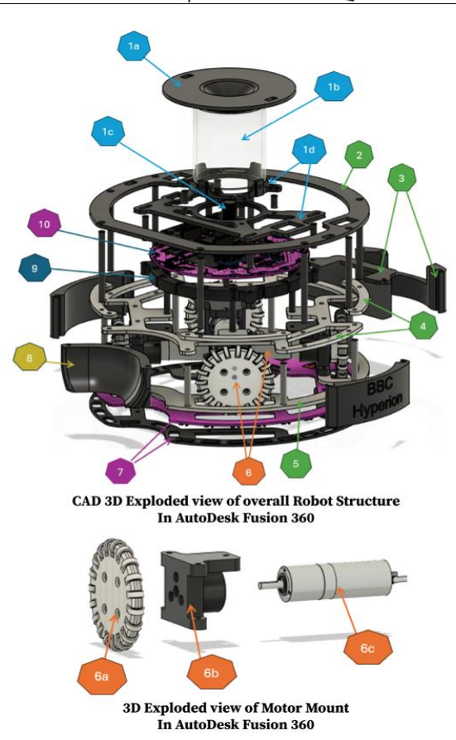
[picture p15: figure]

© RoboCup Junior Australia 2025 | 2 | P a g e

Vision System (1):
The vision system allows the robot to track the goal in a full 360° field of view using a reflective mirror and a single upward-facing camera. It is composed of the following components:
- Cone-Shaped Reflective Mirror (1a):
Reflects the surrounding environment into the camera, enabling a complete horizontal field of view without requiring multiple cameras.
- Clear Acrylic Tube (1b):
Connects the mirror and the camera while allowing light to pass through unobstructed. Unlike standoffs, the tube avoids introducing blind spots in the camera's field of view.
- Upward-Facing OpenMV Camera (1c):
Programmed in MicroPython to process the reflected image and determine the angle to the goal.
- Adjustable PLA Mounting Plates (1d):
Allow calibration of the mirror’s position to correct for misalignments introduced during the manufacturing process.

© RoboCup Junior Australia 2025 | 3 | P a g e

General Frame Design (2, 3, 4, 5)
The robot's structure is built around modular components designed for accessibility, weight distribution, and mechanical strength.
- Top Plate (2):
3D-printed in PLA, the top plate houses key switches and includes a handle for convenient transport and match setup.
- Battery Containment (3):
Comprises a holder and a rear support wall between the mid and base plates. This design secures the battery and minimizes damage caused by movement or impacts.
- Mid & Base Plates (4 & 5):
Made from CNC-machined aluminium to centralize the robot's mass low to the ground, enhancing stability during quick movements and directional changes.

Drive System (6: 6a, 6b, 6c)
The drive system is engineered for multi-directional movement and durability during competitive play. It includes the following elements:
- Custom Omni-Directional Wheels (6a):
Designed with silicon-coated steel rollers for enhanced traction and durability. These rollers are mounted on 3D-printed ABS hubs.
- Motor Brackets (6b):
Custom-made to hold motors in place, ensuring proper alignment and structural integrity.
- High-Performance Motors (6c):
Each wheel is driven by a DCX19 Maxon 9V motor, selected for its compact size and high torque output.

Capture Zone (8)
The ball capture zone is 3D-printed in PLA and designed to increase contact area with the ball. Its curved surface better matches the ball’s shape, reducing sudden impacts and improving control during turns and rapid movement.

PCBs (7 & 10)
Custom PCBs are designed in AutoDesk Fusion 360 and manufactured by JLCPCB for fast turnaround and reliable quality.
- Light Sensor Board (7):
Enables boundary line detection. Protected by a sensor cover that prevents damage from field debris.
- Main Board (10):
Integrates the power supply, microcontrollers, motor controllers, Bluetooth module, and the camera interface.

Component Ratings:
Maxon DCX 19 16:1 Motors x4 (Rating: 5/5) https://www.maxongroup.com/enau/drivesand-systems/brushed-dc-motors (https://www.maxongroup.com/enau/drives-and-systems/brushed-dc-motors)
OpenMV H7 (Rating: 5/5) https://openmv.io/products/openmv-cam-h7-plus?srsltid=AfmBOopUlx-O5g0kAdq29yPygN9NjdEHzttPajDnhGekYY7qRUs_2A8N (https://openmv.io/products/openmv-cam-h7-plus) Teensy 4.1 (Rating: 4.5/5) https://core-electronics.com.au/teensy-4-1.html BNO005 (Rating: 4/5) https://www.amazon.com.au/Precision-Acceleration-GyroscopeGeomagnetic-Smartphones/dp/B0FD8P7FWX (https://www.amazon.com.au/Precision-Acceleration-GyroscopeGeomagnetic-Smartphones/dp/B0FD8P7FWX)
HC-05 (Rating: 4/5) https://www.amazon.com.au/Bluetooth-Pass-Through-WirelessCommunication-Arduino/dp/B01G9KSAF6 (https://www.amazon.com.au/Bluetooth-Pass-Through-WirelessCommunication-Arduino/dp/B01G9KSAF6)

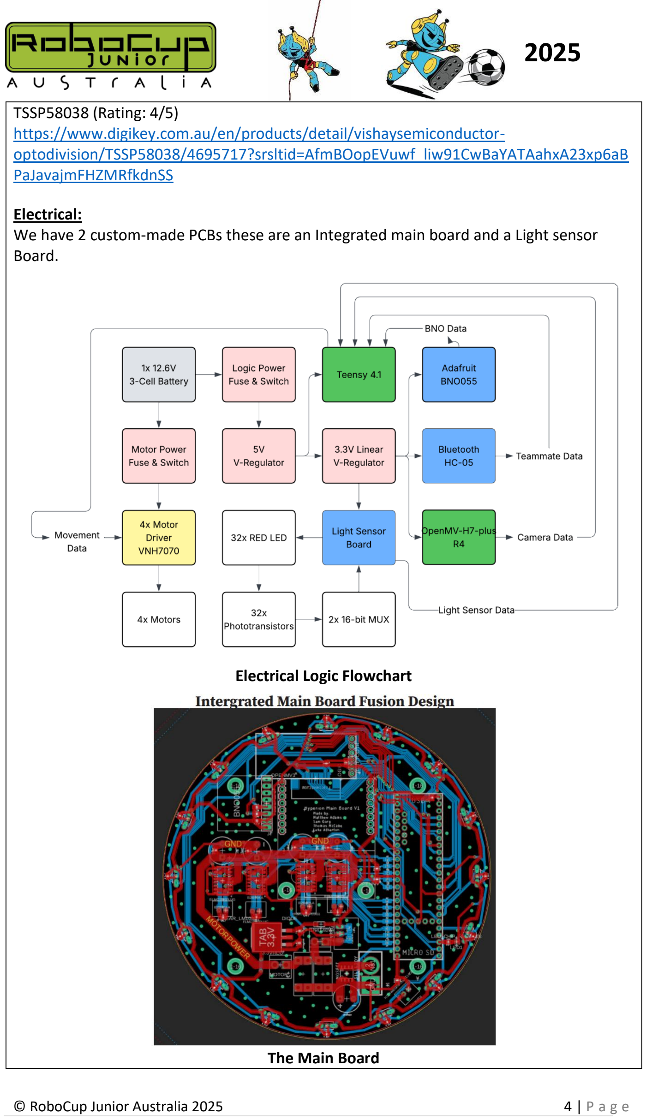
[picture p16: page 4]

© RoboCup Junior Australia 2025 | 4 | P a g e

TSSP58038 (Rating: 4/5)
https://www.digikey.com.au/en/products/detail/vishaysemiconductoroptodivision/TSSP58038/4695717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 PaJavajmFHZMRfkdnSS (https://www.digikey.com.au/en/products/detail/vishaysemiconductor-optodivision/TSSP58038/4695717?)

Electrical:
We have 2 custom-made PCBs these are an Integrated main board and a Light sensor Board.

Electrical Logic Flowchart

The Main Board

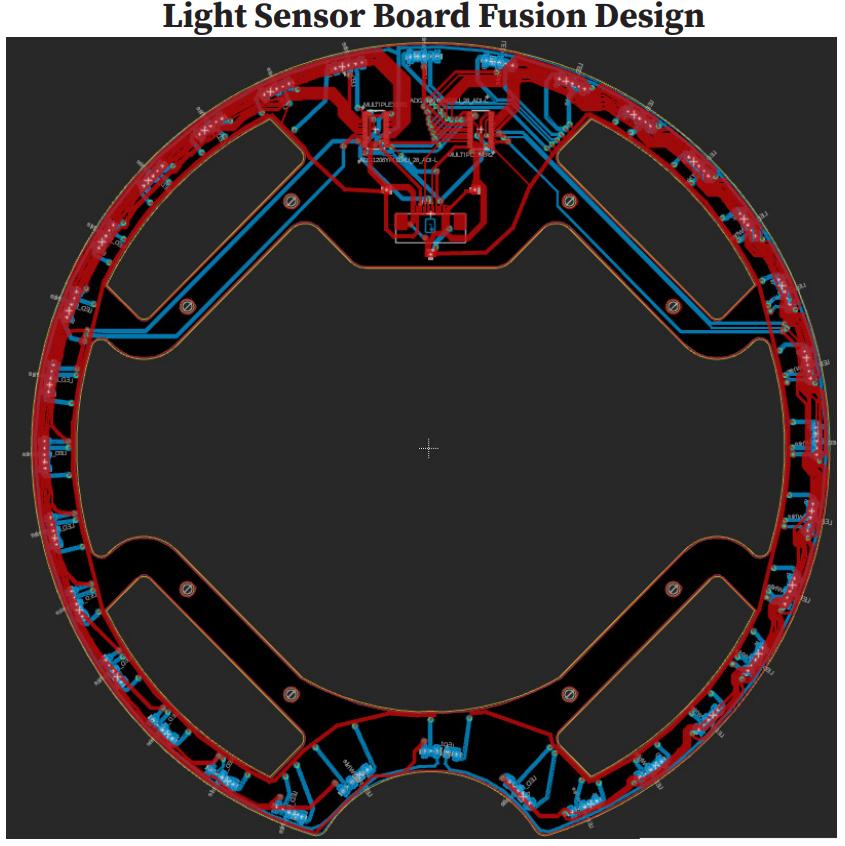
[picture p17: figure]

© RoboCup Junior Australia 2025 | 5 | P a g e

Our main board holds all our important components and the power supply circuit. Since our robot uses a 12.6V 1300mA battery we use a 5V regulator for the Teensy and a 3.3V regulator for the (Camera) OpenMV-H7, (IR Sensors) TSSP58038, (Bluetooth) HC-05, (Compass) BNO005, and the Light sensor board via a FFC connector.

The Light Sensor Board
This PCB contains 32 Red LEDs and 32 Photo transistors. Each LED and Photo transistor is accompanied by resistors and 0.1uf caps. The signals are transferred to 2 16-bit Multiplexers (MUX) 1 for the right side of the board and 1 for the left. These Multiplexers are used for easy reading of many sensors. The outputting binary signals from the Multiplexers get transferred through the FFC to the main board, then to the Teensy.

Software:
In terms of software, we use Visual Studio Code as our primary code editor to write, maintain, and manage our projects. Alongside this, we utilise the PlatformIO extension, which provides powerful tools for compiling code, identifying errors efficiently, and uploading firmware seamlessly to our robot. This setup has proven to be both reliable and efficient. We highly recommend this combination (5/5) to other teams—provided they are using a PlatformIO-supported microcontroller, such as the Teensy 4.1, which we currently use in our system.

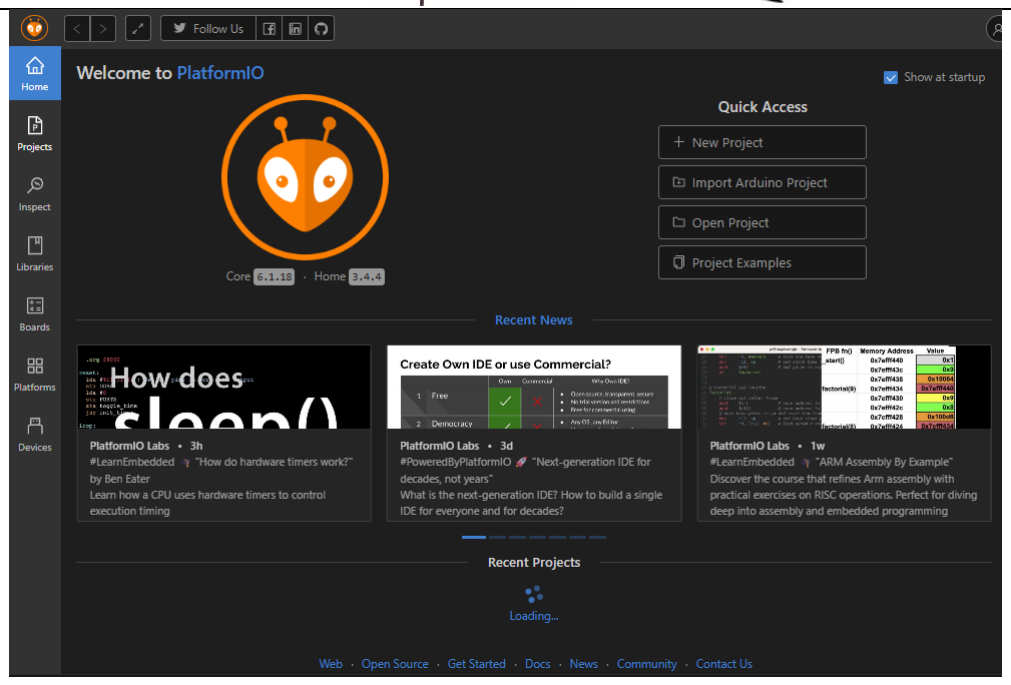
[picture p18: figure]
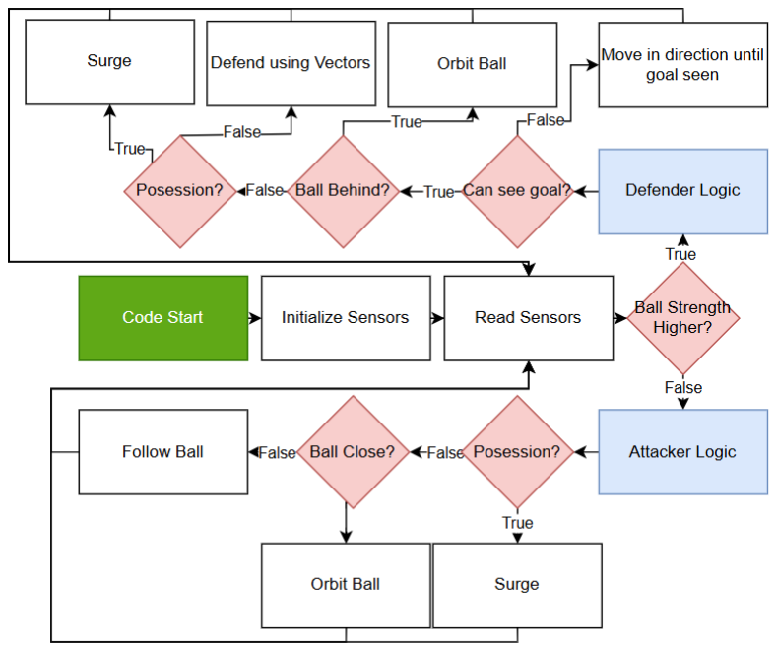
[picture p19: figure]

© RoboCup Junior Australia 2025 | 6 | P a g e

PlatformIO UI and Features (Visual Studio Code)

Software Logic Flowchart (Both Robots at Same Time – Bluetooth Switching)

Collaboration (100 words recommended maximum)
Please describe if your team has used any methodologies, software or systems to aid collaboration (working together). This could be related to the design, construction or programming of the robot(s).

It is the overall desire of RoboCup Junior events that any technological and curricular developments will be shared with other participants after the event. Any developments including new technology and software examples, may be published on the RoboCup Junior website after the event, furthering the mission of RoboCup Junior as an educational initiative.
To communicate, our team uses Microsoft Teams and WhatsApp. Furthermore, to ensure save backups, we use GitHub and email. This ensures that we have a backup should something go wrong locally on our computers at any time.

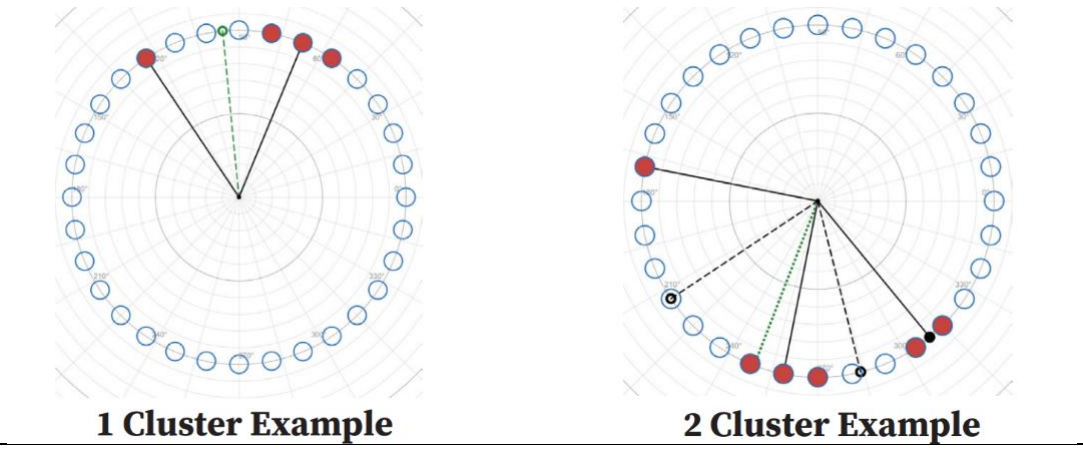
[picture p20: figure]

© RoboCup Junior Australia 2025 | 7 | P a g e

Key Achievement & Area for Improvement (300 words recommended maximum)
Please describe one aspect of your robot your team is particularly proud of, and one aspect you would like to further improve.
Hardware / Electrical:
Key Achievements:
- The omnidirectional vision system was a major achievement. By replacing traditional standoffs with an acrylic tube, we eliminated blind spots and ensured consistent, uninterrupted 360-degree visibility of the goal. The conical mirror, developed through simulation and calculated dimensions, enabled a theoretical 31 metre field of vision. Together, these design choices provided a reliable and efficient vision system that enhanced on-field awareness and performance.
- A further achievement was the transition from PLA to aluminium 6061 for the mid and base plates, significantly improving structural strength and gameplay durability. The new aluminium construction prevented the cracking and failures seen in previous PLA plates during high-speed impacts,
while maintaining manageable weight. This change enhanced the robot’s stability during turns and acceleration, with a lower centre of mass improving traction and overall control in competitive conditions.
- Another key achievement is the custom PCB design, which required precise routing of wide (100 mil) motor traces to minimise electrical resistance. Careful placement of the motor controllers ensured accessibility for quick repair and maintenance during matches, while maintaining a compact and organised layout that connected effectively to the Teensy microcontroller.

Areas for Improvement:
- One key area for improvement is the addition of more advanced components, such as a kicking mechanism. Although refining the core systems was beneficial this year, the absence of a kicker caused missed scoring opportunities, as the ball often became stuck in the goal box.
- Another area identified is ease of maintenance, particularly relating to the main PCB. Electrical issues frequently required extensive disassembly to access internal components, leading to significant delays. Future iterations will aim to redesign the internal layout to improve accessibility, allowing faster component changes and troubleshooting during matches.

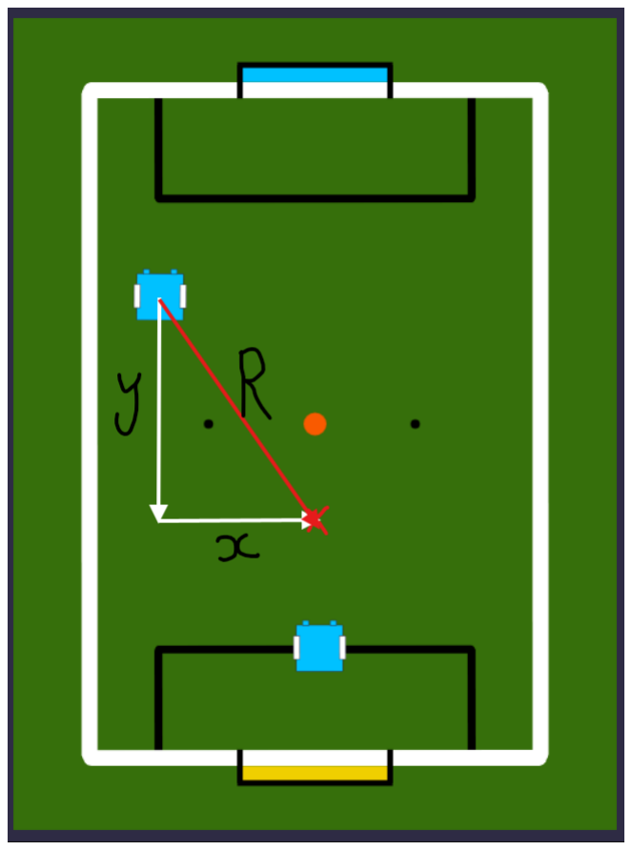
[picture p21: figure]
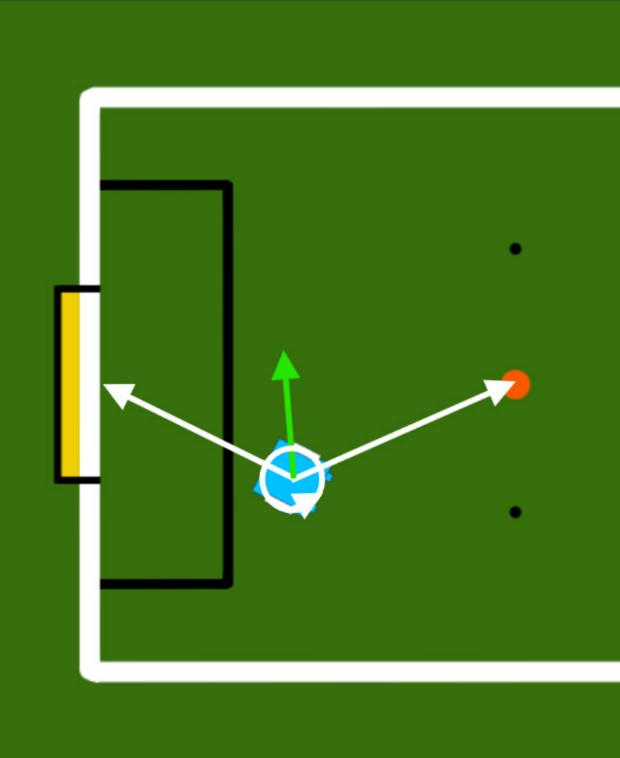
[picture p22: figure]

© RoboCup Junior Australia 2025 | 8 | P a g e

Line Avoidance/Remembrance Cluster Calculation Examples

Attacker Centring Example | Defender Vectors Example
Key Achievements:
- We are particularly proud of our centring and defender logic. Both the attacker and defender are programmed to automatically centre on the field relative to their respective goals when the ball is not detected, allowing for consistent positional awareness and faster reaction times.
Areas for Improvement:
- Improve the reliability and consistency of the out-of-bounds avoidance and line remembrance systems.
- Implement a kicker and dribbler strategy in future versions to enhance offensive capability and goal-scoring efficiency.

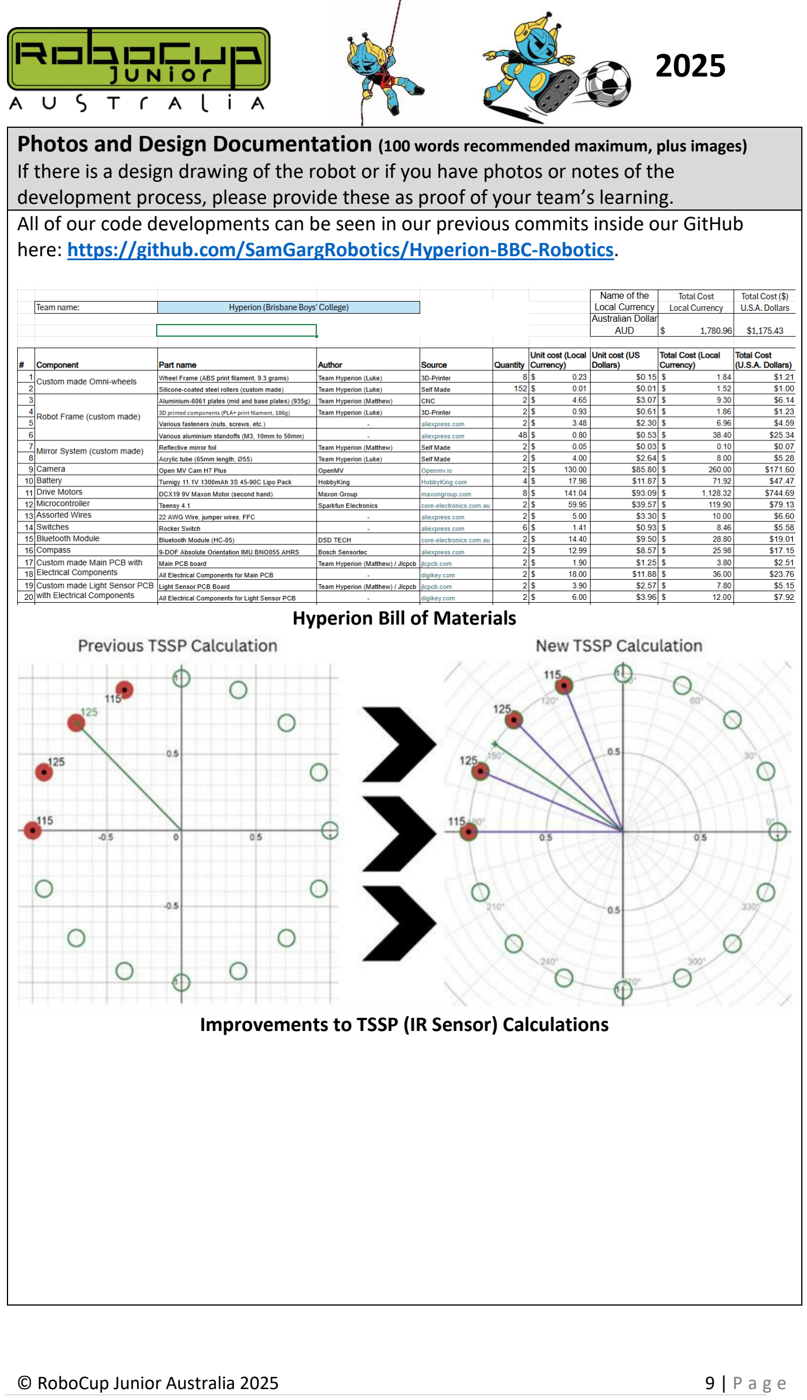
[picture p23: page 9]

© RoboCup Junior Australia 2025 | 9 | P a g e

Photos and Design Documentation (100 words recommended maximum, plus images)
If there is a design drawing of the robot or if you have photos or notes of the development process, please provide these as proof of your team’s learning.
All of our code developments can be seen in our previous commits inside our GitHub here: https://github.com/SamGargRobotics/Hyperion-BBC-Robotics.

Hyperion Bill of Materials

Improvements to TSSP (IR Sensor) Calculations

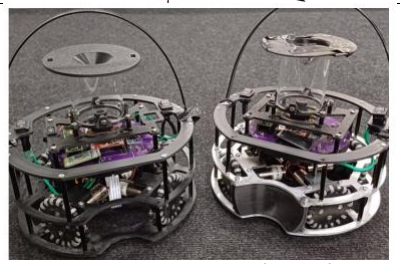
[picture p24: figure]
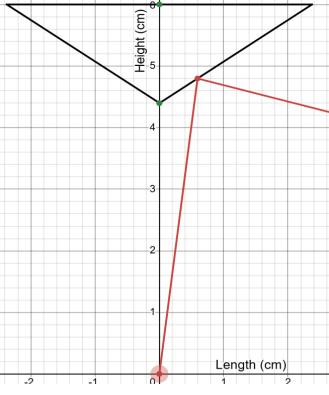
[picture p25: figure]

© RoboCup Junior Australia 2025 | 10 | P a g e

Visual Comparison of Robots (July 2025) Aluminium vs PLA

Mirror Calculations Example Mirror Dimension Simulation Fixed Parameters: Base diameter (23.75 mm), vertical distance from camera to mirror base Variable: Mirror height — determines reflection angle and field of view
Goal of Task: Find optimal mirror height for full field coverage
Method: Simulated ray reflections (mirror radius 2.375 cm) in Desmos → Adjusted mirror angle so reflected ray enters camera just below horizontal → Extended ray to floor (14 cm below camera) to find max range
Result: 16 mm mirror height → ~31 m viewing range (well beyond field, accounts for tolerance)

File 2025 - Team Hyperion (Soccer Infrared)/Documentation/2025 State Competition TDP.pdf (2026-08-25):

© RoboCup Junior Australia 2025 | 1 | P a g e

2025

## RCJA 2025 Rescue Line, Rescue Maze and Soccer Technical Description Paper

Team Information:
Challenge/Division: Lightweight Soccer Team Name: Hyperion
School: Brisbane Boys’ College
State/Territory: Queensland
Team Member Names:
If any team member had a specific role, please include this below. Member 1: Matthew Adams (Hardware/Electrical) Member 2: Sam Garg (Software)
Member 3: Thomas McCabe (Software)
Member 4: Luke Atherton (Hardware/Structural)

Robot Properties (200 words recommended maximum, plus components list (if applicable))
Please describe the software (e.g. EV3 Block Code, Python) and hardware (e.g. Spike Prime, EV3, Raspberry Pi) you have used for your robot.

For each piece of software/hardware used, please give it a star rating out of 5 (1=very bad, would not recommend to other teams, 5=very good, would strongly recommend to other teams).

If you have used custom electronics for your robot, please include specific model/part numbers or web links, and a star rating for each.

Hardware:

Our robots are custom-made with PCBs, PLA Printed Parts, and CNC-machined Aluminium plates. We use the CAD program Autodesk Fusion 360 to create 3D models of parts to test, then decide if they are applicable to implement into our final design. The main things considered when making the design were Size, weight, and easy access to important components, e.g., microcontroller, camera, fuses, battery.

Our robot uses 4 (DCX19 9v Maxon motors) motors for increased power and speed, and to improve balance and control for full 360-degree movement of the robot. For this 360-degree movement to occur, we made omnidirectional wheels, so the robot rolls flawlessly around the field. The wheel frame is made from ABS filament, while the rollers are made from silicone with a metal core. These wheels are positioned around a metal wire to keep them in place.

© RoboCup Junior Australia 2025 | 2 | P a g e

The vision system for our robot consists of adjustable 3d-printed PLA plates (allowing for image centring), an acrylic tube (ensuring no blind spots), a conical mirror (for long range, reliable, 360 goal vision), and the camera itself (OpenMV Cam H7 Plus).

Electrical:

We have 2 custom-made PCBs these are an Integrated main board and a Light sensor board.

The Main Board:

Our main board holds all our important components and the power supply circuit. Since our robot uses a 12.6V 1300mA battery for our motors and motor controllers, we use 2 regulators, which are 5V and 3.3V to power the rest of the board. The main microcontroller runs on 5V while all other components such as the (Camera) OpenMV-H7-plus-R4, (IR Sensors) TSSP58038, (Bluetooth) HC-05, (Compass) BNO005, and the Light sensor board via a FFC connector.

The Light Sensor Board:

This PCB contains 32 Red LEDs and 32 Photo transistors. Each LED and Photo transistor is accompanied by resistors and 0.1uf caps. The signals are transferred to 2 16-bit Multiplexers (MUX) 1 for the right side of the board and 1 for the left. These Multiplexers are used for easy reading of many sensors. The outputs from the Multiplexers are transferred through the FFC to the main board, then transferred to the Teensy.

Software:

In terms of software, we use Visual Studio Code as our primary code editor to write, maintain, and manage our projects. Alongside this, we utilise the PlatformIO extension, which provides powerful tools for compiling code, identifying errors efficiently, and uploading firmware seamlessly to our robot. This setup has proven to be both reliable and efficient. We highly recommend this combination (5/5) to other teams—provided they are using a PlatformIO-supported microcontroller, such as the Teensy 4.1, which we currently use in our system.

Component Ratings:

Maxon DCX 19 16:1 Motors x4 (Rating: 5/5) https://www.maxongroup.com/enau/drives-and-systems/brushed-dc-motors (https://www.maxongroup.com/en-au/drives-and-systems/brushed-dc-motors)

OpenMV H7 plus R4 (Rating: 5/5) https://openmv.io/products/openmv-cam-h7-plus?srsltid=AfmBOopUlx-O5g0kAdq29yPygN9NjdEHzttPajDnhGekYY7qRUs_2A8N (https://openmv.io/products/openmv-cam-h7-plus)

Teensy 4.1 (Rating: 4.5/5) https://core-electronics.com.au/teensy-4-1.html

© RoboCup Junior Australia 2025 | 3 | P a g e

BNO005 (Rating: 4/5) https://www.amazon.com.au/Precision-Acceleration-Gyroscope-Geomagnetic-Smartphones/dp/B0FD8P7FWX (https://www.amazon.com.au/Precision-Acceleration-Gyroscope-Geomagnetic-Smartphones/dp/B0FD8P7FWX)

HC-05 (Rating: 4/5) https://www.amazon.com.au/Bluetooth-Pass-Through-Wireless-Communication-Arduino/dp/B01G9KSAF6 (https://www.amazon.com.au/Bluetooth-Pass-Through-Wireless-Communication-Arduino/dp/B01G9KSAF6)

TSSP58038 (Rating: 4/5) https://www.digikey.com.au/en/products/detail/vishaysemiconductor-optodivision/TSSP58038/4695717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 JavajmFHZMRfkdnSS (https://www.digikey.com.au/en/products/detail/vishay-semiconductor-opto-division/TSSP58038/4695717)

Collaboration (100 words recommended maximum)
Please describe if your team has used any methodologies, software or systems to aid collaboration (working together). This could be related to the design, construction or programming of the robot(s).

It is the overall desire of RoboCup Junior events that any technological and curricular developments will be shared with other participants after the event. Any developments including new technology and software examples, may be published on the RoboCup Junior website after the event, furthering the mission of RoboCup Junior as an educational initiative.

### In terms of collaboration the main ways we managed to work together was through the use of GitHub, Email, Team and Whatsapp. We used GitHub to share and edit each other's code as well as for easy access to prior versions. We used Email to

communicate our absents from sessions as well as sharing word docs like this one.

### We used Team to post notices, and we used What’s app to plan and update people

on what we need to do next.
Key Achievement & Area for Improvement (300 words recommended maximum)
Please describe one aspect of your robot your team is particularly proud of, and one aspect you would like to further improve.
From a hardware perspective, a key achievement would be the design of the vision system. Utilising adjustable plates (ensuring the camera’s vision was centered in OpenMV), an acrylic tube as opposed to standoffs (removing blind spots and allowing for constant, reliable 360-degree goal vision), as well as a conical mirror shape with specifically calculated dimensions (allowing for a theoretical 31m of goal vision with seeing above perpendicular, in all directions), all allowed for a successful vision system from a hardware perspective.

An area for improvement would include the addition of more complex components in future competitions. While refining the basics was beneficial this year, without more complex components such as a kicker, we often found our robot missing goal opportunities, with the ball often getting stuck within the goal box. Furthermore, when experiencing electrical issues, requiring changes to components on our main PCB we often had to largely disassemble our robot, wasting large amounts of time. To improve this in the future we aim to make our design in a way such that our main PCB is more accessible, so changes can be made more efficiently.

© RoboCup Junior Australia 2025 | 4 | P a g e

One of the innovations we are most proud of is the integration of the camera into our main.cpp, which plays a vital role in our robot’s performance. This system allows us to track the goal with high precision, significantly improving our attacker’s accuracy when aiming shots. For the defender, the camera ensures the robot can correctly orient itself away from the goal while maintaining an optimal distance to block incoming shots effectively. Additionally, the camera helps us determine our position on the field, which enables us to implement more advanced strategies.

The parts of our electronics that we are proud of are the design of the PCB. For example, the routing for the motor controllers was difficult and time-consuming because we needed to try and fit 100 mil width traces to reduce resistance in the circuit and have the motor controllers be in an easy-to-access position for easy repair if the motors come unplugged or damaged. Additionally, the motor controllers had to connect to the teensy so space for all the traces had to be considered.

© RoboCup Junior Australia 2025 | 5 | P a g e

Photos and Design Documentation (100 words recommended maximum, plus images)
If there is a design drawing of the robot or if you have photos or notes of the development process, please provide these as proof of your team’s learning.

From a hardware design
perspective, for the
development of the robot
the general proccess started with the designing of the major plates of the design (base and middle plates), then focusing on the drive system components (motor brackets, and wheels), then other major components such as the tssp ring, and capture zone. Then working up, the vision system components and top plate were designed (however a 2nd version of the vision system was later used replacing the original). After such, more minor parts were designed including the battery holder and guard, side guards and LSB protector.

All of our code developments can be seen in our previous commits inside our GitHub here: https://github.com/SamGargRobotics/Hyperion-BBC-Robotics.

Main Board Design | Light Sensor Board Design
Original Robot CAD Design | Final Robot CAD Design

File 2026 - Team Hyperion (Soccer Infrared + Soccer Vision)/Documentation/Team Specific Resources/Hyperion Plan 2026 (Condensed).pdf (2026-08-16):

# Hyperion 2026 Plan (Condensed)

Please note: This is a streamlined version of our full planning document. Some details have been shortened or summarised — for the complete breakdown, refer to the original document.

## Hardware

## Problems identified in 2025

The hardware problems that were identified in 2025 are:
- Wheels didn't have enough grip when robots ran at high speeds (surging) therefore, slid on the field.
- Light sensor board was positioned in a way that it could have shorted when against the aluminium plates, and it was too low to the ground, where it scraped the painted white line at States.
- Mirror was unreliable due to the reflective foil, leading to unwanted reflections
- Robot relied on momentum and couldn’t score from a distance, resulting in wasted battery when surging and missed scores due to overshooting.
- Robot could not always keep possession of the ball and had to rely on angling the robot while moving to guide the ball towards the goal

## Background research

### Wheels – (Luke)

Table () compares the previously used single Omnidirectional wheel to a new Double Omnidirectional wheel.
| Type of Wheel
Key factors | Single Omni-Directional Wheel | Double Omni-Directional
Wheel

Load Capacity

| Lower because rollers handle | Higher because the load is
more stress individually, | distributed across more
reducing overall load capacity. | rollers, allowing greater
support
| Offers less traction, which can | Provides greater traction
Traction & Stability | lead to slipping on smooth | and smoother, more
surfaces. | controlled movement.
Size | Narrow and compact, suitable | Wider area, offering better
for smaller robots or limited | balance and surface
spaces. | contact.

Durability | Rollers wear out faster due to | Increased durability
concentrated stress. | because the rollers share
the load and wear more
evenly.
Maintenance | More affordable but may require | Higher initial cost but
frequent roller replacement. | lower maintenance
frequency over time.

The double omni wheel provides extra grip and stability to the robot while having higher durability for long use.

### Out Avoidance – (Luke)

Due to the larger wheels, table () compares different shapes of light sensor boards to find the best solution for our problem.

Key
Factors
| Shape of Board
Quad perimeter | Outside Wheel Ring | Inside wheel Ring
sections and inner ring

### Mirror – (Luke)

### Capture system – (Matthew)

The capture zone

## Requirements/Restrictions - (Matthew)

Multiple requirements have to be considered in the design process. These requirements are:

## Solutions – (Matthew)

## Electrical

## Problems identified in 2025

The electrical problems that were identified in 2025 are:
- Motor controllers were not easily accessible due to camera
- Camera and Teensy ports were inaccessible due to Bluetooth module
- TSSP’s took too many pins on 1 Teensy 4.1
- LSB routing not optimal
- International communication module not considered in design before ordering PCBs & got reset when logic line switched off
- TSSPs gave inaccurate strength readings
- Robot positioning inaccurate due to mirror/camera limitations

## Background research

### Positioning on the field

Based on past international teams, ultrasonic sensors were used to detect the walls for positioning.
Model | Min/Max Distance | Resolution | Accuracy | Connection Method | Refresh rate | Cost (AUD)
DRFRobot-URM09-Ultrasonic-Distance Sensor | 2cm – 500cm | 1cm | 1% | I 2C | 20ms
HC-SR04-Ultrasonic-Module-Distance-Measuring-Sensor | 2cm – 400 cm | 3mm | 3mm | Digital | 50 – 100ms

## Requirements/Restrictions

Multiple requirements must be considered in the design process. These requirements are:

## Solutions

## Software

## Problem Breakdown

The robot has multiple components incorporated into its design. To combine these components and their uses, an extensive code must be utilised.
Physical Components of our code include Bluetooth, Camera (Teensy & OpenMV Side), Drive System, Light System, TSSP System, Voltage Divider, Compass, Kicker (Mechanics & Strategy), Dribbler (Mechanics & Strategy).
Other Components of our code include the Movement Strategy (Defender & Attacker), PID, and Timers.
These must all be intricately connected in our main.cpp, and must have their respective libraries.

## Background Research

A variety of background research was conducted, as can be seen in the following appendices:

### 1. TSSP System

The ball’s direction can be detected using either vision or infrared systems. A vision-based system like the OpenMV H7 camera can identify the orange ball and coloured goals to estimate position but may lose sight if the ball is obscured. Alternatively, TSSP sensors can detect the ball’s infrared light, offering more reliable and consistent tracking even with visual obstructions.

### 2. Attack Movement Strategy

Background research for this can be seen in Table 1.1 (Appendix).

### 3. Defender Movement Strategy

Background research for this can be seen in Table 1.2 (Appendix).

### 4. Light System

To stay within the field, a robot must detect the white boundary lines, which can be done using light sensors like phototransistors paired with LEDs. These sensors measure reflected light intensity, with white surfaces reflecting more than darker ones. Arranging the sensors and LEDs in a ring around the robot provides 360° coverage, allowing it to detect the line’s presence and direction for corrective movement. This can be achieved by using the clustering method this allows for groups/clusters of sensor to be marked as detecti

Commented [SG1]: Ask tom to fix this up and add more stuff researching what type of line detecting methods can be used ng the line, this allows for the centre of the cluster to be converted into a direction.

### 5. Camera System

OpenMV software uses Python to process images from an OpenMV camera, identifying the ball and goals by color through methods like blob tracking. Data is sent via UART in this order: two start packets, then X and Y coordinates for the yellow goal, blue goal, and ball. The receiving system will use serial functions to read these values and applies equations to calculate each object’s angle and distance:

Angle: f(x, y) = (90 − tan⁻¹

y
x

) mod 360

Distance: f(x, y) = √x
2+y

2

### 6. Bluetooth System

Background Research for this can be seen in Table 1.3 (Appendix).

### 7. Kicker System

To use the kicker effectively, it will only activate when it aids in scoring. A timer prevents excessive firing, and a voltage check ensures sufficient charge before activation. The kicker is triggered by writing HIGH to a digital pin but only when the robot has ball possession (detected via a light gate), is aimed at the goal, and is on the opponent’s side of the field.

### 8. Dribbler System

The robot maintains ball control by detecting when the ball enters its capture zone using ball strength sensors and activating a motor to pull it in. A simple state-based system manages this, keeping the motor off while idle and spinning it forward when the ball is detected, with timing control, current monitoring, and signal filtering improving reliability. For gameplay, the robot can use ball snatching, which is quick but risks losing control, or orbit and dribble, which provides smoother, more accurate positioning and strategic shooting, though slightly slower.

## Specification of Requirements

In order for our robot’s software to be ‘successful’, the following criterion must be met.
1. Ball Detection and Tracking
a. Accurately detect the orange ball using TSSP sensors (Lightweight) or the OpenMV Camera (Open)- (or both).
b. Track ball position in real-time and calculate angle and distance relative to the robot.
c. Maintain ball possession using the dribbler system.
2. Movement and Navigation
a. Implement attack and defender strategies according to the game state.

b. Use motor movement calculations to ensure precise movement and smooth direction changes.
c. Detect and respond to white boundary lines using the light sensor system to stay inside the field.
d. Must be able to score from each neutral point on the field.
3. Goal Detection
a. Use OpenMV camera to detect yellow and blue goals.
b. Calculate angle and distance to opponent’s goal for accurate targeting.
4. Kicker System
a. Only activate the kicker is in possession of the ball, aimed at the opponent’s goal, and on the opponent’s side of the field.
b. Implement a timer and voltage check to prevent premature or excessive kicking.
5. Dribbler System
a. Activate dribbler motor when the ball enters the capture zone.
b. Aide in the possession and accuracy of goal scoring.
6. Communication
a. Send and receive data via Bluetooth for debugging or external control.
b. Receive position data from the OpenMV camera via UART in the correct packet format.
7. System Integration
a. Ensure all components (camera, TSSP, dribbler, kicker, light sensors, PID, timers, motors) operate in coordination.
b. Maintain real-time performance for gameplay decisions.
8. Reliability Requirements
a. All software routines must handle unexpected data safely (e.g. Noise, Division by Zero in angle calculations).

## Brainstorm, Evaluate and Choose Solutions

Ball Detection:
- Options: TSSP sensors only, OpenMV camera only, or hybrid system.
- Camera: Accurate angle/distance and goal detection but can fail if ball is obscured.
- TSSP: Lightweight, reliable infrared detection, works even if ball is partially hidden.
- Chosen solution: TSSP’s (Lightweight), Camera (Open)
Movement Strategy - Attack
- Options: Cases, Exponential/Quadratic, PID

- Chosen solution: Exponential/Quadratic as it has a smooth curvature, medium processing demand, stable and predictable.
Boundary Detection
Dribbler & Kicker Activation
- The dribbler and kicker will be used to maintain possession, only being triggered when a certain amount of power is available, and when the ball is close enough.
- Adds timers, current monitoring, and signal filtering for reliability. Communication
- Bluetooth will be used for switching communication and advanced strategy.
- UART to receive camera position data in correct packet format.
Integration & Final Solution
- All components integrated via main.cpp: camera, TSSP, dribbler, kicker, light sensors, PID, timers, and motors.
- Software loop:
- Read sensors → calculate angle/distance → decide strategy → control motors & actuators.
Ultimate Robot Function:
- Detects and tracks the ball reliably.
- Maintains possession using dribbler.
- Navigates field safely and avoids boundaries.
- Scores efficiently with the kicker.
- Adapts between attacking and defending strategies.
- Operates reliably in real-time under game conditions.

Commented [SG2]: Ask tom to do this

# Appendix

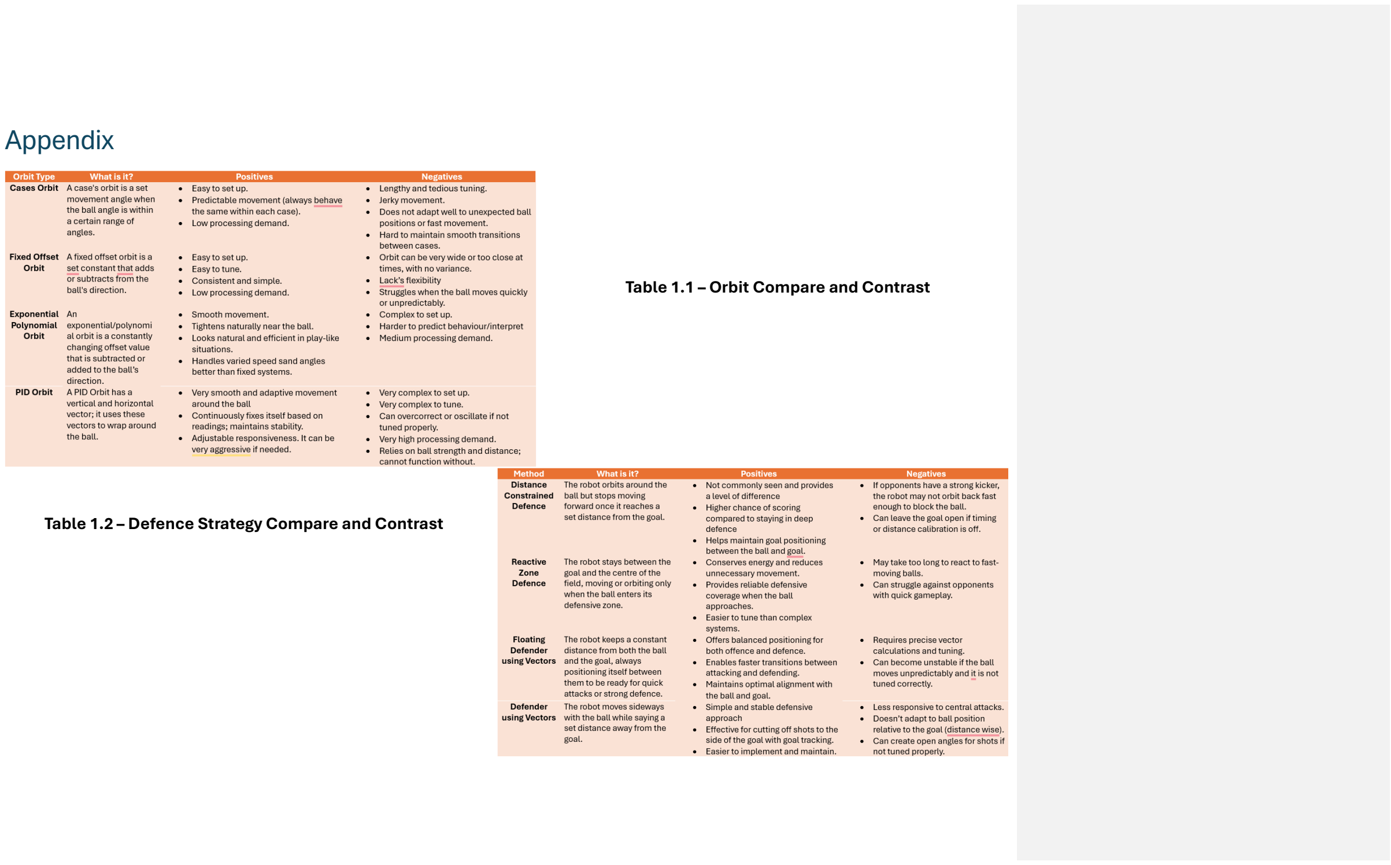
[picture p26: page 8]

Table 1.1 – Orbit Compare and Contrast

Table 1.2 – Defence Strategy Compare and Contrast

Table 1.3 – Bluetooth Strategy Compare and Contrast


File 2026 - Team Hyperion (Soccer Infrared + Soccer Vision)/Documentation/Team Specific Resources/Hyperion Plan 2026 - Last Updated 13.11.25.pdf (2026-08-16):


# Team Hyperion

## 2026 Planning and Documentation

Team Hyperion 2026 Planning

## Contents

## Abstract

Hyperion is an Australian robotics team from Brisbane Boys’ College, competing in the RoboCup Junior International Soccer Lightweight League and RoboCup Junior Australia Soccer Open League. The team consists of four secondary students who have developed two fully autonomous soccer robots for the upcoming 2026 RoboCup competitions. After building on two years of experience in the RoboCup Junior Soccer League in both the 2024 and 2025 seasons, our goal is to enhance the mechanical reliability, sensor accuracy, gameplay strategy and consistency of our robots.

## Team Members

Hardware Role
Matthew Adams: (Mechanical & Electrical)
Matthew's robotics journey began in 2018. He quickly developed foundational skills in basic coding and problem-solving using Lego EV3 and NXT, which soon expanded to include CAD designing and modelling, as well as the ability to read electrical schematics and design and solder PCBs while understanding their functionality. His dedication to robotics is reflected in his continuous learning and commitment. Matthew has actively participated in multiple RoboCup Junior Australia (RCJA) competitions, earning impressive results such as 4th place in both State and National events, including Onstage in 2021, 3rd place in the Lightweight division at States in 2024, and 2nd place at the National competition that same year. These achievements highlight his growing expertise, passion, and competitive spirit within the robotics community.
Luke Atherton: (Mechanical & Structural)
Luke began his robotics journey in 2019, initially exploring foundational coding and Lego EV3 robotics. His skills soon broadened to include CAD design, 3D modelling, soldering, and hands-on hardware construction. Over the years, Luke has remained a dedicated and consistent presence in the RoboCup Junior Australia (RCJA) community, competing across multiple disciplines. His achievements include 2nd place in the Open Line Rescue division at the 2022 State competition and 5th nationally the same year. In 2023, he played a key role in his team’s 2nd place finish at the State competition and 6th nationally in the Standard Soccer League. His continued success carried into 2024, earning 3rd place at States and 2nd place at Nationals in the Lightweight Soccer League. These results reflect Luke’s growing technical expertise, collaborative mindset, and competitive drive.

Software Role
Sam Garg: (Software & Strategy)
Sam started robotics in 2018. Over the years, he has developed proficiency in a wide range of programming languages, including EV3 and Spike block coding, EV3 MicroPython, Spike Python, RobotC, and C++ within the Arduino framework. His passion and dedication to robotics have been demonstrated through consistent participation in RoboCup Junior Australia (RCJA) competitions. Notable achievements include placing 4th in both the Queensland State and National OnStage competitions in 2021, securing 2nd at State and 6th Nationally in the Standard Soccer League in 2023, and most impressively, finishing 3rd in the State Soccer League and 2nd in the National Lightweight Soccer League in 2024. These accomplishments highlight Sam’s growth, technical skill, and competitive spirit in the field of robotics.
Thomas McCabe: (Software & Vision)
Thomas McCabe began his robotics journey in 2019, quickly developing a strong foundation across multiple platforms and programming environments. He has gained proficiency in languages such as Spike Block, EV3 Block, Spike MicroPython, EV3 MicroPython, and RobotC. Thomas has demonstrated consistent commitment to the field through years of participation in RoboCup Junior Australia (RCJA) competitions. His notable achievements include competing in the RCJA OnStage Challenge in 2021, advancing through RCJA Secondary Rescue in 2022 and 2023, and most recently, earning a 3rd place finish at the State level in the RCJA Soccer Standard League in 2024. These milestones reflect not only Thomas’s technical progression but also his resilience and enthusiasm for robotics.

## Software Planning

## Assignments

Aspects | Assigned To | Individual | Overall | Status
| | Order | Order
Bluetooth | Sam | 3 | 6 | Complete
(26/10/25)
Camera (Teensy | Sam | 2 | 5 | Complete
Side) | | | | (30/10/25)
Camera (OpenMV | Tom | 3 | 4 | Complete
Side) | | | | (29/10/25)
Drive System | N/A (Prev.) | N/A (Prev.) | N/A (Prev.) | Complete
(Prev.)
Light System | Tom | 2 | 3

PID | N/A (Prev.) | N/A (Prev.) | N/A (Prev.) | Complete
| | | | (Prev.)
TSSP System | Tom | 1 | 1 | Complete
| | | | (29/10/25)
Timer | N/A (Prev.) | N/A (Prev.) | N/A (Prev.) | Complete
| | | | (Prev.)
Voltage Divider(s) | N/A (Prev.) | N/A (Prev.) | N/A (Prev.) | Complete
| | | | (Prev.)
Compass | N/A (Prev.) | N/A (Prev.) | N/A (Prev.) | Complete
| | | | (Prev.)
Kicker Mechanics | Sam | 4 | 7 | Complete
| | | | (26/10/25)
Dribbler Mechanics | Tom | 5 | 9
Kicker Strategy | Tom | 4 | 8
Dribbler Strategy | Sam | 5 | 10 | Awaiting
Mechanics
Side
Movement | Sam | 1 | 2 | Complete
Strategy | | | | (21/10/25)
Common | Shared | Shared | Shared | Shared
Configuration | Shared | Shared | Shared | Shared
Pins | Shared | Shared | Shared | Shared

## General Conventions

Variables – Camel Case
Class Names – Camel Case with a capital starting letter
Function and Struct Names – lower case separated by underscores

## 1. TSSP System – Thomas McCabe

Define Problem

In order for the robot to gain possession of the ball and score, it must first be able to determine the direction of the ball relative to itself.

Key Question:
How can the direction of the ball relative to the robot be accurately determined? Background Research

There are several possible methods for detecting and determining the relative direction of the ball.
Since the competition ball is orange, one option is to use a vision-based system such as the OpenMV H7 camera. This camera can identify coloured objects — for example, yellow and blue goals, and an orange ball — allowing the robot to estimate the ball’s position. However, this approach has limitations, such as the camera’s frame rate and potential loss of visual contact if the ball is obscured.

Alternatively, the competition ball emits infrared (IR) light, which can be detected using TSSP sensors. Infrared light has the advantage of being less affected bytea visual obstructions, making this method generally more reliable for continuous tracking. Requirements
- The offset values of each TSSP sensor must be easy to adjust.
- The system must provide a consistent and reliable measure of ball signal strength.
- The program must execute quickly and efficiently on the Teensy microcontroller. Plan for Solution
The proposed solution involves reading data from each TSSP sensor 255 times and summing the digital outputs (0 or 1) to calculate a total value for each sensor. The sensor with the highest total value indicates the direction of the ball, expressed in degrees relative to the robot.

Functions
Name | Description
init_tssp | To set up the pins and their types
read_tssp | To read all the tssp and find ball dir and str
get_ball_dir | Returns ball dir
get_ball_str | Returns ball str

## 2. Movement Strategy – Sam Garg

Attacker
Define Problem
To not constantly hit the ball towards the defending goal, the robot must have a movement strategy to effectively get behind the ball and move it towards the opponent’s goal.
What kind of attacking movement strategy should the robot have?

Background Research
There are many different types of orbits/movement strategies, which can include:
Orbit Type | What is it? | Positives | Negatives
Cases Orbit | A case's orbit is a set | • Easy to set up. | • Lengthy and tedious tuning.
| movement angle when | • Predictable movement (always behave | • Jerky movement.
| the ball angle is within | the same within each case). | • Does not adapt well to unexpected ball
| a certain range of | • Low processing demand. | positions or fast movement.
angles.
- Hard to maintain smooth transitions between cases.
Fixed Offset | A fixed offset orbit is a | • Easy to set up. | • Orbit can be very wide or too close at
Orbit | set constant that adds | • Easy to tune. | times, with no variance.
| or subtracts from the | • Consistent and simple. | • Lack’s flexibility
| ball's direction. | • Low processing demand. | • Struggles when the ball moves quickly
or unpredictably.
Exponential | An | • Smooth movement. | • Complex to set up.
Polynomial | exponential/polynomi | • Tightens naturally near the ball. | • Harder to predict behaviour/interpret
Orbit | al orbit is a constantly | • Looks natural and efficient in play-like | • Medium processing demand.
changing offset value
that is subtracted or
added to the ball’s
direction.

situations.
- Handles varied speed sand angles better than fixed systems.
PID Orbit | A PID Orbit has a | • Very smooth and adaptive movement | • Very complex to set up.
| vertical and horizontal | around the ball | • Very complex to tune.
| vector; it uses these | • Continuously fixes itself based on | • Can overcorrect or oscillate if not
| vectors to wrap around | readings; maintains stability. | tuned properly.
| the ball. | • Adjustable responsiveness. It can be | • Very high processing demand.
| | very aggressive if needed. | • Relies on ball strength and distance;
cannot function without.

Requirements
The orbit movement strategy must:
- Be easy to tune and adjust.
- Position the robot efficiently behind the ball.
- Prevent unwanted contact with the ball (from sides or rear)
- Adapt to different ball speeds and movement patterns.
- How low to medium processing demand (to optimise the loop speed)
- Be stable and predictable
- React quickly to sensor data
- Maintain smooth curvature in its orbit path
- Allow for scalable complexity (make it more advanced)
- Minimize overshooting
Plan for Solution
Based on the background research and the outlined requirements, an Exponential Orbit strategy will be implemented in the program. This method will rely on a single constant to tune the overall orbit behaviour.
1. A modified ball direction will be calculated, ranging from -180° to 180°. This allows both sides to be mirrored, ensuring the robot produces symmetrical movement on either side of the ball.
2. A movement scalar will be determined based on the ball’s position. This value will range between 0 and 1 and follow an exponential curve, allowing for smoother and more responsive movement as the ball gets closer.
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

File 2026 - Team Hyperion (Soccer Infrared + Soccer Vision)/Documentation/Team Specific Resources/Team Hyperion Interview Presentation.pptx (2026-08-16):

## TEAM HYPERIOn


SAM GARG, MATTHEW ADAMS, LUKE ATHERTON AND THOMAS MCCABE

## STRUCTURAL

Something something

## Electrical

Something something

## SOFTWARE | TSSP SYSTEM

Tom

## SOFTWARE | TSSP SYSTEM

Tom

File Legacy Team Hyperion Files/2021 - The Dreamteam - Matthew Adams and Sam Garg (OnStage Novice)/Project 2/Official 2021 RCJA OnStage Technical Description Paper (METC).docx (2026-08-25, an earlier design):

RCJA 2021 OnStage Technical Description Paper

Team Information

Division: Novice

Team Name: Error 404

School: Brisbane Boys College

State/Territory: Queensland

Team Member Names:

If any team member had a specific role, please include this below.

Member 1: Sam Garg

Member 2: Matthew Adams

Member 3: Christopher Ashley

Member 4:

Member 5:

## Collaboration

It is the overall desire of RoboCup Junior events that any technological and curricular developments will be shared with other participants after the event. Any developments including new technology and software examples, may be published on the RoboCup Junior website after the event, furthering the mission of RoboCup Junior as an educational initiative.
Scoring Added to the Technical Interview Score | /10 | Novice | Experienced
Demonstrates that the work on display is authentic | | /6 | /4
Hardware development process clearly indicated | | /1 | /2
Performance concept development process clearly indicated | | /1 | /2
Software development process clearly indicated | | /2 | /2

## Summary

What is the theme/performance/idea of The Performance? What is the main highlight in your Performance? What sensors should the audience look out for?

The performance/idea of the performance is that it revolves around The Chicken Dance. The main highlight of the performance is that it moves around with the music. A sensor that the audience should look for is the Compass.
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

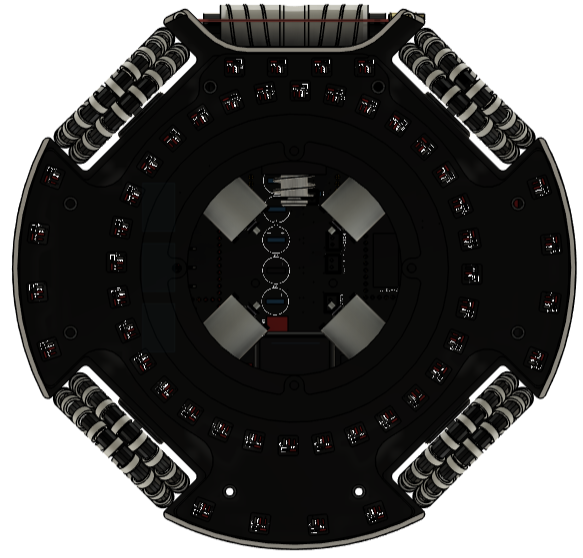
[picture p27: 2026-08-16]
2026 - Team Hyperion (Soccer Infrared + Soccer Vision)/Hardware/Robot Design Photos/Screenshot 2026-06-05 101749.png

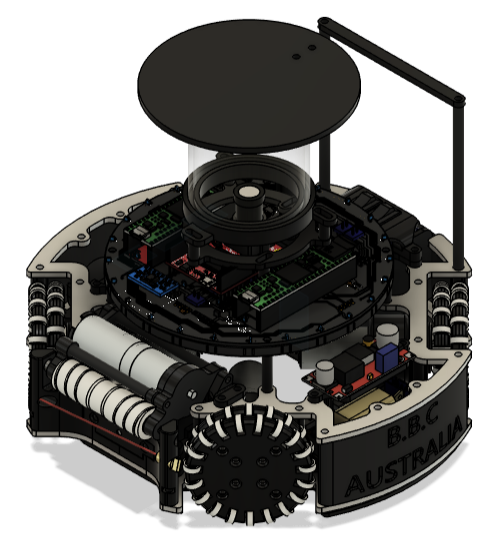
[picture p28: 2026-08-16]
2026 - Team Hyperion (Soccer Infrared + Soccer Vision)/Hardware/Robot Design Photos/Screenshot 2026-06-05 101702.png

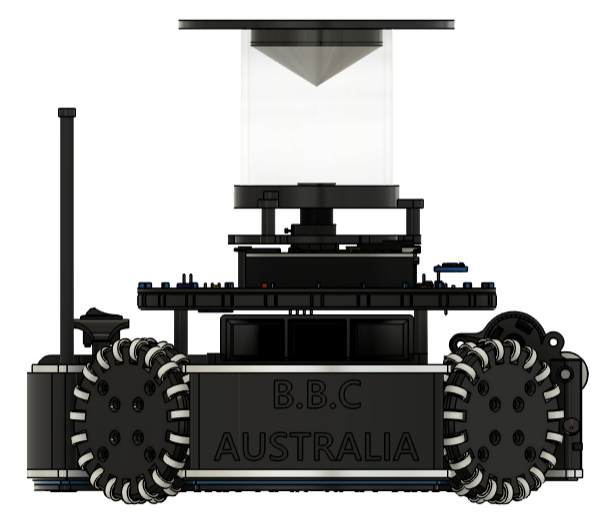
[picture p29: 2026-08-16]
2026 - Team Hyperion (Soccer Infrared + Soccer Vision)/Hardware/Robot Design Photos/Screenshot 2026-06-05 101638.png

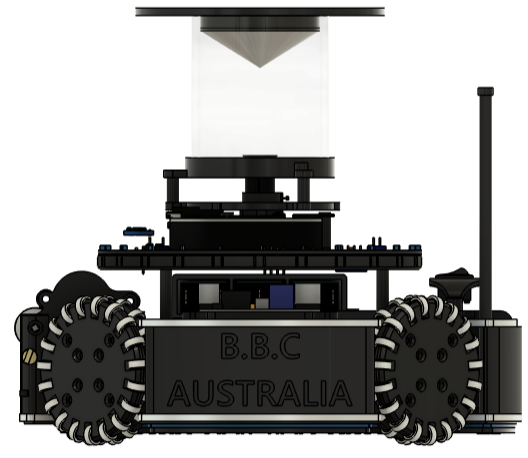
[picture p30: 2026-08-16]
2026 - Team Hyperion (Soccer Infrared + Soccer Vision)/Hardware/Robot Design Photos/Screenshot 2026-06-05 101553.png

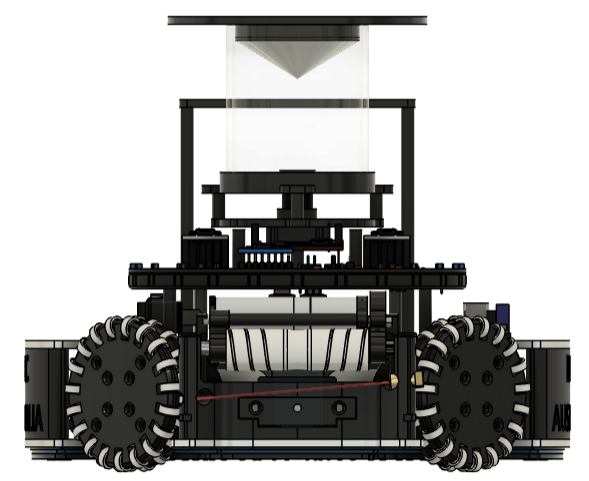
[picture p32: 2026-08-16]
2026 - Team Hyperion (Soccer Infrared + Soccer Vision)/Hardware/Robot Design Photos/Screenshot 2026-06-05 101536.png

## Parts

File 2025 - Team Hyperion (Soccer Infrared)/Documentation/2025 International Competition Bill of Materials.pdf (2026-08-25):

## Team name:

# | Component | Part name

1 | Custom made Omni-wheels | Wheel Frame (ABS print filament, 9.3 grams)
2 | | Silicone-coated steel rollers (custom made)
3 | Robot Frame (custom made) | Aluminium-6061 plates (mid and base plates) (935g)
4 | 3D printed components (PLA+ print filament, 186g)
5 | | Various fasteners (nuts, screws, etc.)
6 | | Various aluminium standoffs (M3, 10mm to 50mm)
7 | Mirror System (custom made) | Reflective mirror foil
8 | | Acrylic tube (65mm length, Ø55)
9 | Camera | Open MV Cam H7 Plus
10 | Battery | Turnigy 11.1V 1300mAh 3S 45-90C Lipo Pack
11 | Drive Motors | DCX19 9V Maxon Motor (second hand)
12 | Microcontroller | Teensy 4.1
13 | Assorted Wires | 22 AWG Wire, jumper wires, FFC
14 | Switches | Rocker Switch
15 | Bluetooth Module | Bluetooth Module (HC-05)
16 | Compass | 9-DOF Absolute Orientation IMU BNO055 AHRS
17 | Custom made Main PCB with Electrical Components | Main PCB board
18 | | All Electrical Components for Main PCB
19 | Custom made Light Sensor PCB with Electrical Components | Light Sensor PCB Board
20 | | All Electrical Components for Light Sensor PCB
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
## Hyperion (Brisbane Boys' College)

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
Author | Source | Quantity
Team Hyperion (Luke) | 3D-Printer | 8
Team Hyperion (Luke) | Self Made | 152
Team Hyperion (Matthew) | CNC | 2
Team Hyperion (Luke) | 3D-Printer | 2
- | aliexpress.com | 2
- | aliexpress.com | 48
Team Hyperion (Matthew) | Self Made | 2
Team Hyperion (Luke) | Self Made | 2
OpenMV | Openmv.io | 2
HobbyKing | HobbyKing.com | 4
Maxon Group | maxongroup.com | 8
Sparkfun Electronics | core-electronics.com.au | 2
- | aliexpress.com | 2
- | aliexpress.com | 6
DSD TECH | core-electronics.com.au | 2
Bosch Sensortec | aliexpress.com | 2
Team Hyperion (Matthew) / Jlcpcb | jlcpcb.com | 2
- | digikey.com | 2
Team Hyperion (Matthew) / Jlcpcb | jlcpcb.com | 2
- | digikey.com | 2

Name of the Local Currency | Total Cost Local Currency
Australian Dollar AUD | $ 1,780.96
Unit cost (Local Currency) | Unit cost (US Dollars) | Total Cost (Local Currency)
$ 0.23 | $0.15 | $ 1.84
$ 0.01 | $0.01 | $ 1.52
$ 4.65 | $3.07 | $ 9.30
$ 0.93 | $0.61 | $ 1.86
$ 3.48 | $2.30 | $ 6.96
$ 0.80 | $0.53 | $ 38.40
$ 0.05 | $0.03 | $ 0.10
$ 4.00 | $2.64 | $ 8.00
$ 130.00 | $85.80 | $ 260.00
$ 17.98 | $11.87 | $ 71.92
$ 141.04 | $93.09 | $ 1,128.32
$ 59.95 | $39.57 | $ 119.90
$ 5.00 | $3.30 | $ 10.00
$ 1.41 | $0.93 | $ 8.46
$ 14.40 | $9.50 | $ 28.80
$ 12.99 | $8.57 | $ 25.98
$ 1.90 | $1.25 | $ 3.80
$ 18.00 | $11.88 | $ 36.00
$ 3.90 | $2.57 | $ 7.80
$ 6.00 | $3.96 | $ 12.00

## Total Cost ($) U.S.A. Dollars

(U.S.A.
$1.21
$1.00
$6.14
$1.23
$4.59
$25.34
$0.07
$5.28
$171.60
$47.47
$744.69
$79.13
$6.60
$5.58
$19.01
$17.15
$2.51
$23.76
$5.15
$7.92

$1,175.43

## Team name:

# | Name | Software's Tool/Library | Description

1 | Visual Studio Code | Software Tool | Used for developing the software on the robot
2 | Platformio.io | Software Tool | Used as a compiler for the robot to upload and debug the robot
3 | AdafruitBNO055 | Library | Used for reading the compass
4 | Adafruit Sensor | Library | Used for reading the compass
5 | PID | Library | Used for tuning movement and direction based on different environments
6 | Timer | Library | Used to create timer based on instances in the code
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
## Hyperion (Brisbane Boys' College)

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
Name of the Local Currency | Total Cost Local Currency | Total Cost ($) U.S.A. Dollars
Australian Dollar | $0.00 | $0.00
Source | Autor | Currency) | Dollars)
VSC Download (https://code.visualstudio.com/download) | Microsoft Corporation | FREE | FREE
Install Platformio (https://platformio.org/install) | PlatformIO Labs | FREE | FREE
Team Polarity GitHub (https://github.com/BBCRobo/Polarity-2022/tree/main/lib/Adafruit_BNO055_Master) | Adafruit | FREE | FREE
Team Polarity GitHub (https://github.com/BBCRobo/Polarity-2022/tree/main/lib/Adafruit_Sensor) | Adafruit | FREE | FREE
Team Polarity GitHub (https://github.com/BBCRobo/Polarity-2022/tree/main/lib/PID) | Team Polarity BBC | FREE | FREE
Team Alphatron GitHub (https://github.com/Junpeng-Huang/Alphatron-Ints-V1-2024/tree/main/lib/_Timer) | Junpeng Huang | FREE | FREE

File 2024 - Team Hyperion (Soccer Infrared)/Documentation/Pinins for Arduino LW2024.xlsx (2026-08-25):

D13 | Motor 1
D12 | Motor 2
D11 | Motor 3
D10 | Motor 4
D9
D8
D7
D6
D5
D4
D3
D2
D1/TX
D0/RX
C14 | Camera
C15 | Camera
C16
C17
C18
C19
C20 | Compass
C21 | Compass
D22 | Motor 1
D23 | Motor 1
D24 | Motor 2
D25 | Motor 2
D26 | Motor 3
D27 | Motor 3
D28 | Motor 4
D29 | Motor 4
D30 | Tssp
D31 | Tssp
D32 | Tssp
D33 | Tssp
D34 | Tssp
D35 | Tssp
D36 | Tssp
D37 | Tssp
D38 | Tssp
D39 | Tssp
D40 | Tssp
D41 | Tssp
D42
D43
D44
D45
D46
D47
D48
D49
D50
D51
D52
D53
A0 | Light Sensor
A1 | Light Sensor
A2 | Light Sensor
A3 | Light Sensor
A4 | Light Sensor
A5 | Light Sensor
A6 | Light Sensor
A7 | Light Sensor
A8 | Light Sensor
A9 | Light Sensor
A10 | Light Sensor
A11 | Light Sensor
A12 | Light Sensor
A13 | Light Sensor
A14 | Light Sensor
A15 | Light Sensor

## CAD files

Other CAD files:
2025 - Team Hyperion (Soccer Infrared)/Hardware/Battery_holder.f3d
2025 - Team Hyperion (Soccer Infrared)/Hardware/LSB_Protector.f3d
2025 - Team Hyperion (Soccer Infrared)/Hardware/acrylic_tube_mount_part 1.f3d
2025 - Team Hyperion (Soccer Infrared)/Hardware/arcrylic_tube_mount_part_2.f3d
2025 - Team Hyperion (Soccer Infrared)/Hardware/base_plate.f3d
2025 - Team Hyperion (Soccer Infrared)/Hardware/battery_door.f3d
2025 - Team Hyperion (Soccer Infrared)/Hardware/capture_zone_v2.f3d
2025 - Team Hyperion (Soccer Infrared)/Hardware/ir_ring_v1.f3d
2025 - Team Hyperion (Soccer Infrared)/Hardware/mid_plate.f3d
2025 - Team Hyperion (Soccer Infrared)/Hardware/mirror_attachement.f3d
2025 - Team Hyperion (Soccer Infrared)/Hardware/motor_holder.f3d
2025 - Team Hyperion (Soccer Infrared)/Hardware/omni_wheel_part_1.f3d
2025 - Team Hyperion (Soccer Infrared)/Hardware/omni_wheel_part_2.f3d
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

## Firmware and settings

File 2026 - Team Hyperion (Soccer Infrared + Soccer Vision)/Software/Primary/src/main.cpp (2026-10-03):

#include <Arduino.h>
#include "Adafruit_BNO055.h"
#include "Ball_handling.h"
#include "Bluetooth.h"
#include "Camera.h"
#include "Common.h"
#include "Config.h"
#include "Drive_system.h"
#include "Light_system.h"
#include "PID.h"
#include "Timer.h"
#include "Voltage_divider.h"
 
///////////////////////////////////// FSMs ////////////////////////////////////
enum RobotState {
    STATE_IDLE,
    STATE_CALIBRATE,
    STATE_GAME
};

//////////////////////////////////// OBJECTS //////////////////////////////////
// ROBOT SYSTEMS
Adafruit_BNO055 bno(BNO055_SENSOR_ID, BNO055_ADDRESS_B, &Wire);
BallHandling ballHandler;
Camera cam;
DriveSystem motors;
LightSystem ls;
Bluetooth bt;

// PIDs
PID correction(KP_IMU, 0.0, KD_IMU, IMU_PID_MAX);
PID goalTrackAttack(KP_GOALT_ATK, 0.0, KD_GOALT_ATK, GOALT_PID_MAX);
PID goalTrackDefend(KP_GOALT_DEF, 0.0, KD_GOALT_DEF, GOALT_PID_MAX);
PID horizontal(KP_HOZT, 0.0, 0.0);
PID vertCam(KP_CVERT, 0.0, KD_CVERT);
PID lineAvoid(KP_LAV, 0.0, KD_LAV, LAV_PID_MAX);
PID localise(KP_LOC, 0.0, KD_LOC, LOC_PID_MAX);
// VOLTAGE DIVIDERS
VoltageDivider battery(ROBOT_VD_PIN, ROBOT_VOLTAGE_STABALISER, ROBOT_VOLTAGE_OFFSET);
 
// TIMERS
Timer batteryTimer(BATTERY_TIMER_INTERVAL);
Timer localiseTimer(LOCALISE_TIMER_INTERVAL);
 
// FINITE STATE MACHINES
RobotState state;
 
// EVENTS
sensors_event_t event;
 
// VARIABLES
float target = 0.0f;
float bearing;
 
float relBallDir = 0.0f;
float relBallStr = 0;
int surgeTimer = -1;
 
float relLineAngle = -1.0f;
float relLineSize = -1.0f;
bool onField = true;
float absLineAngle = -1.0f;
float absLineSize = -1.0f;
 
float batLvl = 0.0f;
 
bool lastMotorsOn = false;
 
Vect attackGoal;
Vect defendGoal;
Vect ballData;
Vect fieldPosition;
Vect otherFieldPosition;
Vect otherBallData;
 
 
/////////////////////////////////// FUNCTIONS /////////////////////////////////

//! @brief Make a vector relative to the field rather than the robot
//! @param v Vector that is being converted
Vect absoluteVector(Vect v) {
    if(v.exists()) {
        return Vect(v.mag, float_mod(bearing + v.arg, 360.0f), true);
    } else {
        return Vect(0.0f, 0.0f, true);
    }
}
 
//! @brief Update field position vector based on goal vectors
void update_field_vectors() {
    otherFieldPosition = bt.get_other_pos();
    otherBallData = bt.get_other_ball();

    // Convert all camera vectors relative to field
    Vect globalAttack = absoluteVector(attackGoal);
    Vect globalDefend = absoluteVector(defendGoal);
    Vect globalBall = absoluteVector(ballData);

    // The vector of the goals relative to the center of the field
    Vect attackGoalPos(FIELD_LENGTH_MM / 2.0f, 0.0f, true);
    Vect defendGoalPos(-FIELD_LENGTH_MM / 2.0f, 0.0f, true);

    if (attackGoal.exists() && defendGoal.exists()) {
        // If the attack goal and defend goal exist
        Vect posFromAttack = attackGoalPos - globalAttack;
        Vect posFromDefend = defendGoalPos - globalDefend;
        fieldPosition = (posFromAttack + posFromDefend) / 2.0f;
    } else if (attackGoal.exists()) {
        // If only the attack goal exists
        fieldPosition = attackGoalPos - globalAttack;
    } else if (defendGoal.exists()) {
        // If only the defend goal exists
        Vect tempGoal = Vect(globalDefend.mag, float_mod(globalDefend.arg + 180.0f, 360.0f), true);
        fieldPosition = tempGoal + defendGoalPos;
    } else {
        // If no goals exist
        fieldPosition = Vect(0.0f, 0.0f, false);
    }
}
 
//! @brief Update the line direction and line size relative to that of the field
void update_absolute_line() {
    relLineAngle = ls.get_line_angle();
    relLineSize = ls.get_line_size();
    bool noLine = (relLineAngle == -1.0f);
    float lineDirection = noLine ? -1.0f : float_mod(relLineAngle + bearing, 360.0f);
 
    if (onField) {
        if (!noLine) {
            absLineAngle = lineDirection;
            absLineSize = relLineSize;
            onField = false;
        }
    } else {
        if (absLineSize == LINE_OUTSIDE_SIZE) {
            if (lineDirection != -1.0f && smallestAngleBetween(lineDirection, absLineAngle) >= LINE_TOUCH_REENTRY_ANGLE) {
                absLineAngle = float_mod(lineDirection + 180.0f, 360.0f);
                absLineSize = 2.0f - relLineSize;
            }
        } else {
            if (noLine) {
                if (absLineSize <= LINE_INSIDE_THRESH) {
                    onField = true;
                    absLineAngle = -1.0f;
                    absLineSize = -1.0f;
                } else {
                    absLineSize = LINE_OUTSIDE_SIZE;
                }
            } else {
                if (smallestAngleBetween(lineDirection, absLineAngle) <= 90.0f) { 
                    absLineAngle = lineDirection;
                    absLineSize = relLineSize;
                } else {
                    absLineAngle = float_mod(lineDirection + 180.0f, 360.0f);
                    absLineSize = 2.0f - relLineSize;
                }
            }
        }
    }
}
 
//! @brief Adjusts the movement direction and speed if the line is seen
//! @param mDir The current movement direction of the robot.
//! @param mSpd The current movement speed of the robot.
void line_avoid(float &mDir, float &mSpd) {
    #if LIGHT_SENSORS
    if (absLineSize != -1.0f) {
        // If the line is detected
        
        if (relBallStr == 0.0f) {
            // If we don't see the ball, then simply move in the opposit edirection of the line
            mDir = float_mod(absLineAngle + 180.0f, 360.0f);
            mSpd = -lineAvoid.update(absLineSize, -1.0f);
        } else if (absLineSize < LINE_AVOID_THRESH) {
            // If the robot is moving towards the line, and it is not too far past, stay onthe line
            if (smallestAngleBetween(mDir, absLineAngle) < 90.0f) {
                mSpd = sin(smallestAngleBetween(mDir, absLineAngle) * DEG_TO_RAD) * LS_SLIDE_CONST;
                float difference = normaliseAngle180(float_mod(mDir - absLineAngle, 360.0f));
                if (difference > 0.0f) {
                    mDir = float_mod(absLineAngle + 90.0f, 360.0f);
                } else {
                    mDir = float_mod(absLineAngle - 90.0f, 360.0f);
                }
            }
        } else {
            // The robot should move away from the line if it sees the ball but is way over
            mDir = float_mod(absLineAngle + 180.0f, 360.0f);
            mSpd = -lineAvoid.update(absLineSize, -1.0f);
        }

    }
    #endif
}
 
//! @brief Orbit algorithm, calculates how we actually move behind the ball.
//! @param mDir The current movement direction of the robot.
//! @param mSpd The current movement speed of the robot.
void orbit(float &mDir, float &mSpd) {
    float absBallDir = float_mod(relBallDir + bearing, 360.0f);
    float orbitTarget = 0.0f;

    // Adjust the "target" based on where the goal is
    if (attackGoal.exists() && GOAL_TRACKING) {
        orbitTarget = float_mod(bearing, 360.0f);
    }

    // Algorithm deciding how much "angle" to add to the current ball direction
    #if ORBIT
    #if CONTROL
    float dir = normaliseAngle180(float_mod(absBallDir - orbitTarget, 360.0f));
    float ballAngDiff = (dir > 0.0f ? 1.0f : -1.0f) * fmin(90.0f, -0.000000264461f*pow(dir, 4) + 0.0000136593f*pow(dir, 3) + 0.0183734f*dir*dir - 0.129586f*dir + 10.0f);
    float distMulti = 0.6f;
    float angleAddition = distMulti * ballAngDiff;
    #else
    float dir = normaliseAngle180(float_mod(absBallDir - orbitTarget, 360.0f));
    float ballAngDiff = (dir > 0.0f ? 1.0f : -1.0f) * fmin(90.0f, 0.000000309786f*pow(dir, 4) + 0.0000534514f*pow(dir, 3) + 0.0163822f*dir*dir - 0.00204537f*dir + 10.0f);
    float distMulti = 0.8f;
    float angleAddition = distMulti * ballAngDiff;
    #endif

    // Move forward at full speed if the robot sees the ball infront of it, close enough, or if the light gate is triggered
    #if SURGE
    if((((absBallDir < BALL_FRONT_MIN && absBallDir > BALL_FRONT_MAX) && (relBallStr < BALL_STR_CLOSE_THRESH)) || ballHandler.photogate_triggered())) {
        mDir = 0.0f;
        mSpd = SURGE_SPEED;
    } else {
        mDir = float_mod(absBallDir + angleAddition, 360.0f);
        mSpd = BASE_SPEED + (SURGE_SPEED - BASE_SPEED) * (1.0f - fabs(angleAddition / 90.0f));
    }
    #else
    mDir = float_mod(absBallDir + angleAddition, 360.0f);
    #endif
    #endif
}

//! @brief Attack code algorithm - scores goals
void run_attack() {
    float moveDir = 0.0f;
    float moveSpd = 0.0f;
    float moveCor = 0.0f;
 
    if (relBallStr != 0.0f || ballHandler.photogate_triggered()) {
        // If we can see the ball, orbit
        localiseTimer.update();
        orbit(moveDir, moveSpd);
    } else {
        // If we haven't seen the ball for a certain period of time, we can localise
        #if LOCALISATION
        if (localiseTimer.time_has_passed_no_update()) {
            moveDir = float_mod(fieldPosition.arg + 180.0f, 360.0f);
            moveSpd = fabs(localise.update(fieldPosition.mag, 0.0f));
        } else {
            moveDir = 0.0f;
            moveSpd = 0.0f;
        }
        #else
        moveDir = 0.0f;
        moveSpd = 0.0f;
        #endif
    }

    line_avoid(moveDir, moveSpd);

    if (onField) {
        float facingError = (attackGoal.exists() && GOAL_TRACKING)
            ? fabsf(normaliseAngle180(float_mod(attackGoal.arg, 360.0f)))
            : fabsf(normaliseAngle180(bearing));
        if (facingError <= 15.0f) {
            // We are facing the goal
            if(attackGoal.mag > GOAL_DIST_FOR_KICKER_ENABLE) {
                // If we are close enough to the attack goal
                if(ballData.exists()) {
                    // If the ball data exists and the ball is infront, kick
                    if((ballData.arg < BALL_FRONT_MIN && ballData.arg > BALL_FRONT_MAX)) {
                        Serial.println("kick1");
                        ballHandler.kick();
                    }
                } else {
                    // If the ball data does not exist, kick
                    ballHandler.kick();
                    Serial.println("kick2");
                }
            }
        }
    }
 
    // Goal Track
    if (attackGoal.exists() && GOAL_TRACKING) {
        float goalAngle = normaliseAngle180(float_mod(attackGoal.arg, 360.0f));
        moveCor = goalTrackAttack.update(goalAngle, 0.0f);
    } else {
        moveCor = -correction.update(normaliseAngle180(bearing), 0.0f);
    }
 
    motors.run(moveSpd, float_mod(moveDir - bearing, 360.0f), moveCor);
}

//! @brief Defend code algorithm - helps concede less goals
void run_defend() {
    float moveDir = 0.0f;
    float moveSpd = 0.0f;
    float moveCor = 0.0f;
    bool ballBehind = (relBallDir > 90.0f && relBallDir < 270.0f) && ballData.exists();
    float bearingCor = -correction.update(normaliseAngle180(bearing), 0.0);

    // Serial.println(defendGoal.mag);
    if ((relBallDir < 10.0f || relBallDir > 350.0f) && relBallStr <= 200){
        moveCor = -correction.update(normaliseAngle180(bearing), 0.0f);
        motors.run(100, relBallDir, moveCor);
    } else if(ballBehind) {
        // Orbit and face forward if ball behind
        orbit(moveDir, moveSpd);
        moveCor = bearingCor;
        motors.run(moveSpd, float_mod(moveDir - bearing, 360.0f), moveCor);
    } else {
        if(defendGoal.exists()) {
            // Rotational PID, face towards the goal
            float goalAngle = float_mod(defendGoal.arg + 180.0f, 360.0f);
            moveCor = goalTrackDefend.update(normaliseAngle180(goalAngle), 0.0f);
            // Vertical PID, stay optimal distance away from goal
            float vert = vertCam.update(defendGoal.mag, DEFEND_CAM_TARGET);
            // Hotizontal PID, move towards ball
            // If the ball does not exist, center to the middle of the field
            float hozt = horizontal.update((relBallStr != 0.0f) ? -normaliseAngle180(relBallDir) : normaliseAngle180(bearing), 0.0f);
            //hozt = 0.0f;
            // float hozt = horizontal.update(-normaliseAngle180(relBallDir), 0.0f);
            // Kick when the ball is in the capture zone
            if(onField) {
                ballHandler.kick();
            }
            moveSpd = sqrtf(hozt*hozt + vert*vert);
            moveDir = (atan2f(hozt, vert) * RAD_TO_DEG);
        } else {
            // If we cannot see the defend goal, move backwards
            moveSpd = 70.0f;
            moveDir = 180.0f;
        }
    }

    line_avoid(moveDir, moveSpd);
    motors.run(moveSpd, moveDir, moveCor);
}
 
//! @brief Turns battery LED on when robot battery becomes low
void update_battery_led() {
    batLvl = battery.get_lvl();
 
    if (batLvl > ROBOT_REQUIRED_VOLT) {
        batteryTimer.update();
        digitalWrite(BATTERY_LED, LOW);
    } else if (batteryTimer.time_has_passed_no_update()) {
        digitalWrite(BATTERY_LED, HIGH);
    } else {
        digitalWrite(BATTERY_LED, LOW);
    }
}

void setup() {
    state = STATE_IDLE;

    // Initialise all components
    while (!bno.begin(OPERATION_MODE_IMUPLUS)) {
        Serial.println("No BNO055 detected.");
        delay(1000);
    }
 
    cam.init();
    motors.init();
    ls.init();
 
    bt.init();
    battery.init();
 
    ballHandler.init();
    pinMode(ENABLE_SWITCH, INPUT);
    pinMode(BATTERY_LED, OUTPUT);
}
 
void loop() {
    update_battery_led();
    bool motorsOn = digitalRead(ENABLE_SWITCH);

    // Decide state based on enable switch.
    if (!motorsOn) {
        state = STATE_IDLE;
    } else if (!lastMotorsOn) {
        state = STATE_CALIBRATE;
    }
 
    switch (state) {
        case STATE_IDLE:
            // Stop running motors
            motors.run(0.0f, 0.0f, 0.0f);
            break;
 
        case STATE_CALIBRATE:
            // Reset compass heading
            bno.getEvent(&event);
            target = event.orientation.x;
            ls.reset_line();
            state = STATE_GAME;
            break;
 
        case STATE_GAME: {
            // Update compass heading
            bno.getEvent(&event); 
            bearing = float_mod(event.orientation.x - target, 360.0f);
 
            // Update camera data
            cam.update();
            attackGoal = cam.get_attack();
            defendGoal = cam.get_defend();
            ballData = cam.get_ball();
            relBallDir = ballData.arg;
            relBallStr = ballData.mag;
            update_field_vectors();
 
            // Update light sensor board data
            ls.update();
            update_absolute_line();
 
            // Update robot logic based on bluetooth
            // if (bt.get_role()) {
            if(CONTROL) {
                run_attack();
            } else {
                run_defend();
            }
            break;
        }
    };
 
    ballHandler.update(relBallStr);
    bt.update(motorsOn, ballData, fieldPosition, ballHandler.kicker_ready());
    lastMotorsOn = motorsOn;
}

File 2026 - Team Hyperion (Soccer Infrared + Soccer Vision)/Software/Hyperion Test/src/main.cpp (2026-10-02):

#include <Arduino.h>
#include <Pins.h>
#include <Ball_handling.h>
// #include <Drive_system.h>

BallHandling ballHandler;



void setup() {
  ballHandler.init();
  pinMode(ENABLE_SWITCH, INPUT);
}

void loop() {
  ballHandler.update(80.0f);
  Serial.print(ballHandler.kicker_ready());
  Serial.print("\t");
  Serial.println(ballHandler.can_kick());
  if(digitalRead(ENABLE_SWITCH)) {
    ballHandler.kick();
  }
}

// it will not kick without the enable switch being on, so if you want it to
// dribble and then kick, you can leave the enable switch off and then turn it on when you want to kick
// up to you how you want to do it,


// this will print 2 things, one if the kicker is ready (without photogate)
// two: it will print if it is ready to kick with photogate, if this prints one that means it probably just kicked
// realistically, just worry about the first number as the 2nd one will only be there for like 10 loops (really quick)

// the code has been uploaded

// hold on, is this how much time is left for it to kick?

// that is quite hard as it is its own timer class, I can print if it is READY to kick, is that okay?
// 

// ok enable switch now ok

// im literally writing power to them regardless of anything, so there has tobe something wrong wiring wise

// This has photogate as well btw - so it wont kick if the photogate is not activated
// speak herew
// is bluetooth 

// that doesnt do anything im literally just writing power to dribb at 100/255

// what does that do its writing to the pin manually- you cant print nothing

// no because this is a completely seperate file on its own

// click enable switch, but shouldnt kick until ball is in capture

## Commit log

2026-08-14 CAMERA.PY ACTUAL WORK
2026-08-14 Camera.py Fixes and Optimisations
2026-08-14 Update CameraBetter.py to work on Chaos - States
2026-08-15 Camera.py works good
2026-08-15 Camera.py now works
2026-08-15 Camera Does not Send Goals
2026-08-16 Uploaded CAD Files
    Uploaded all CAD Files
    [Australia Brace Bar.f3d, Battery Cage.f3d, Battery Door v1.f3d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]
2026-08-16 Populated Documentation
    [Ball Direction & Strength Values with and without an EMA filter.xlsx, Hyperion LS Values Sheet.xlsx]
2026-08-21 Main.cpp IT Test Revert
    [main.cpp]
2026-08-25 Recategorised Repository
    [Australia Brace Bar.f3d, Ball Direction & Strength Values with and without an EMA filter.xlsx, Battery Cage.f3d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]
2026-08-27 Vectors don't compile in light system and camera
2026-08-27 Robot Battery LED works
2026-08-27 Ligh Test + Fix
    [main.cpp]
2026-08-31 Adding to Camera.py
    changing cam py to use timLib.Point2D
    to simplify code
2026-09-07 Camera Testing with New Mirror
2026-09-09 Motor Weird Issue Testing
    [main.cpp]
2026-09-16 Goal Track Var Cleanup
2026-09-17 Out Avoidance + Attack + Defend Algorithms Work
    However, to make it work in the comp you have to tune the algorithm- however as a baseline this works
    [main.cpp]
2026-09-17 Bluetooth Sending / Receiving Works - Some Logic Issues Though
    [main.cpp]
2026-09-21 switching is sort of working
2026-09-21 Tuned Camera Thresholds
2026-09-21 Camera Tuned
2026-09-22 Cam Tubed
2026-09-22 bt switching control up
2026-09-22 Small Camera Changes
2026-09-22 Small Camera Updates
2026-09-25 Localisation & Camera Logic Changes
2026-09-25 Defense - Wait for Kick before Switch
2026-09-25 Added Tangential Avoidance Switching :) (Logic)
    [main.cpp]
2026-09-29 Switching Logic works + looptime 2.5ms :)
2026-10-03 Added Defender Surge Case
2026-10-03 Hardcoded Robot Roles (No Switching for Now)
2026-10-03 After Nationals Day 1 - Currently Placing 1st
2026-10-03 Line Reset
    Im GITING I AM GIT-ING
    [main.cpp]
2026-10-03 Updated Switching Algorithm (Similar to 2025)

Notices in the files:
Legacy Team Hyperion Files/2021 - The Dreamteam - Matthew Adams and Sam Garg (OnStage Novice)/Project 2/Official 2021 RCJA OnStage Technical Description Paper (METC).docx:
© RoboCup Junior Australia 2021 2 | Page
